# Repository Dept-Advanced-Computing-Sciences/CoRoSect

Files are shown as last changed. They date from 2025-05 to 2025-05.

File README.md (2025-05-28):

# CoRoSect
Results from the Horizon Project CoRoSect

<ul>
     <li>Robot Extension - STEP and mechanical design files for the robot extension used in CoRoSect</li>
     <li>scripts - contains additional scripts and files
     <ul>
       <li>reachability_simulation: URDF design of robot extension and simulation scripts.</li>
       <li>stabilization_secondary_planning_scene: ROS launch files for a secondary MoveIt! environment where iterative stabilisation is performed.</li>
     </ul>
     </li>

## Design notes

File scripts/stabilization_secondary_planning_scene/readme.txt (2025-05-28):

The main script that performs iterative planning for a constrained rail orientation is ins linear_drive_constrained_planning.py. 
It relies on a definition of your robot URDF as a planning group in MoveIt! and referenceing the correct link IDs.
This script can be run individually or through ROS. Through ROS, it opens a service (.srv files are included but need to be compiled).

The new planning scene should be launched in a secondary ROS NAMESPACE to not link the with either the primary MoveIt! planning scene or the real robot.
This is done through the fake_world.launch, which can be included to run automatically within another launch file.

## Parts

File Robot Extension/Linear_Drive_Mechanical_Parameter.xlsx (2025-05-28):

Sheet: LS_Main_Functional_Parameter
Linear drive specs |  |  | Wittenstein CDS040 main motor specs without any gears
Parameter | Symbol | Value | Parameter | Symbol | Value | Parameter | Symbol | Value
Max speed sled | vs_max | 1 m/s | No load speed |  | 5087 rpm
Max travel distance of sled on linear drive | d_max | 0.45 m
Max acceleration of sled | a_max | 3.9 m/s^2 | Max torque |  | 1.02 Nm
Time required by sled to travel 450 mm | t_450 | 0.75 sec | Cont. stall torque |  | 0.32 Nm
 |  |  | Weight |  | 650 g

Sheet: LS_Weight table
Linear slide weight table
# | Part | Weight in grams | Amount | Total | Category | Sub Category
1 | 40x40 V-slot | 604.517 | 1 | 604.517 | Rail Assembly | Aluminium Extrusion
2 | Pulley | 12.189 | 1 | 12.189 | Rail Assembly | Pulleys
3 | PRT-02-20-P | 72.8569 | 1 | 72.8569 |  | Bearings
4 | Wheel Assembly | 24.1229 | 4 | 96.4916 |  | DOF1/Sled
5 | Belt Fastener Assembly | 32.799 | 2 | 65.598 |  | DOF1/Sled
6 | Bottom Sled | 298.839 | 1 | 298.839 |  | Aluminium part - milled
7 | KUKA End | 442.027 | 0 | 0
8 | CDSR-040CHM0-00000-1SG-E | 647.039 | 3 | 1941.117 |  | DOF1
9 | Top Sled | 100.817 | 1 | 100.817 |  | Aluminium part - milled
10 | Bearing | 6.71 | 2 | 13.42 |  | Bearings
11 | Connector Plate Motor | 43.501 | 1 | 43.501 | Rail Assembly
12 | Connector Plate KUKA | 128.117 | 1 | 128.117 | Rail Assembly
13 | RG6 Quickchanger Flange | 56.138 | 1 | 56.138
14 | RG6 | 1352.65 | 1 | 1352.646
15 | Mounting Plate Pulley | 31.655 | 2 | 63.31 | Rail Assembly | Pulleys
16 | Pulley Protection 1 | 78.401 | 1 | 78.401 |  | Printed parts
17 | Pulley Protection 2 | 78.358 | 1 | 78.358 |  | Printed parts
19 | M3x12 Low | 0.8449 | 4 | 3.3796 |  | Screws and bolts
20 | M6x14 Sunken | 2.934 | 8 | 23.472 |  | Screws and bolts
21 | M5x16 Sunken | 2.294 | 8 | 18.352 |  | Screws and bolts
22 | Shaft 2nd DOF | 123.948 | 1 | 123.948
23 | Spacerblock 2nd DOF | 53.729 | 1 | 53.729 |  | Aluminium part - milled
24 | Armature Type 300-SZ04-6Hk7 | 29.541 | 1 | 29.541
25 | SHSWA 15-25 | 33.769 | 2 | 67.538
26 | Adapter RG6 Quickchanger | 61.58 | 1 | 61.58
27 | Ball Bearing SS | 4.131 | 2 | 8.262 |  | Bearings
28 | Spurgear SSY1 90 M | 205.554 | 1 | 205.554 |  | Spurgears
29 | Spurgear SUS1 25J8 | 53.889 | 1 | 53.889 |  | Spurgears
30 | 90370A20T Steel Thin Hex Nut | 0.291 | 3 | 0.873 |  | Screws and bolts
31 | Adapter Plate DOF1 to DOF2 | 30.759 | 1 | 30.759 |  | Aluminium part - milled
32 | 92855A522 18-8 SS | 1.604 | 3 | 4.812 |  | Screws and bolts
33 | Mounting Plate 2nd DOF | 40.227 | 1 | 40.227 |  | Aluminium part - milled
34 | 90965A160 316 SS | 0.175 | 10 | 1.75 |  | Screws and bolts
35 | 90037A119 316 HS | 1.286 | 4 | 5.144 |  | Screws and bolts
36 | Brake Krendion PM Line 86 61 | 176.89 | 1 | 176.89
37 | 9375A195 18-8 SS | 0.018 | 6 | 0.108 |  | Screws and bolts
38 | 91292A834 18-8 SS | 0.137 | 6 | 0.822 |  | Screws and bolts
39 | Spurgear SSG1 20J8 | 29.432 | 1 | 29.432 |  | Spurgears
40 | MLHS10 | 5.093 | 1 | 5.093
41 | Spurgear SSG1 80C | 221.019 | 1 | 221.019 |  | Spurgears
42 | DOF2 Mount | 110.093 | 1 | 110.093 |  | Aluminium part - milled
43 | DOF2 Mount 18-8 SS Hex | 0.282 | 4 | 1.128 |  | Screws and bolts
44 | 90751A123 18-8 SS | 1.438 | 6 | 8.628 |  | Screws and bolts
45 | End Stop Bar | 4.688 | 2 | 9.376 |  | Aluminium part - ordered
46 | Bird drinker/Feader | 1309.339 | 0 | 0
 |  |  |  | 6301.7151 | gr.

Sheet: LS_Inertias_and_Torques
Linear Drive Moments and Inertias and Moments of Inertias
Part/ Assembly | Weight | Moment of Inertia around movement axis [gmm^2] | [kgcm^2] | [kgm^2] | Load torque TL* | Acc. Torque Ta* | Total Torque*
Full linear drive assembly | 6136 g | - | - | - | - | -
Full linear drive assembly with filled bird drinker | 7436 g | - | - | - | - | -
Sledge with dof 2 (yawing) and dof 3 (tilting) incl RG6 | 4560 g | - | - | - | - | -
Sledge with dof 2 and dof 3 incl RG6 + Filled bird drinker | 5870.1 g | - | - | - | - | -
Dof 2 (Yawing) with RG6 in vert. position | 3318.4 g | 7.255*10^6 | 0.7 (72.55) | 0.00073 (0.0073) | - | -
Dof 2 (Yawing) with RG6 in hor. position | 3318.4 g | 3.539*10^7 | 3.6 (360??) | 0.00036 (0.035) | - | 1.02 Nm ( @t_t=0.5 sec, d_t=90° a=28.3 rad/sec^2) | 1.53 Nm T=(Ta+TL)*Sf with Sf=1.5
Dof 2 (Yawing) with RG6 in vert. position + filled bird drinker | 4627.7 g | 1.009*10^7 | 1 (100) | 0.0001 (0.01) | - | -
Dof 2 (Yawing) with RG6 in hor. position + filled bird drinker | 4627.7 g | 1.457*10^8 | 14.6 (1500) | 0.00146 (0.15) | - | 0.041 Nm ( @t_t=0.5 sec, d_t=90° a=28.3 rad/sec^2) | 0.0620 Nm T=(Ta+TL)*Sf with Sf=1.5
Dof3 (Tilting) with RG6 | 1917.5 g | 1.158*10^7 | 1.2 (120) | 0.00012 (0.012) | 1.63 Nm (@hor. Pos.,@COM to shaft distance = 0.1 m, @1.66 kg) | 0.034 Nm ( @t_t=0.5 sec, d_t=90° a=28.3 rad/sec^2) | 1.66 Nm T=(Ta+TL)*Sf with Sf=1.5
Dof3 (Tilting) with RG6 + filled bird drinker | 3226.8 g | 4.480*10^7 | 4.5 (450) | 0.00045 (0.045) | 5.48 Nm (@hor. Pos.,@COM to shaft distance = 0.188 m, @2.97 kg) | 0.13 Nm ( @t_t=0.5 sec, d_t=90° a=28.3 rad/sec^2) | 5.61 Nm T=(Ta+TL)*Sf with Sf=1.5
 |  |  |  | *Torques required without considering gear ratios. To get torques required by the motors divide the torque values by the corresponding gear ratios
Torques on KUKA iiwa joint A6
Configuration | Total weight of drive [Kg] | Distance of COM to A6 [m] | Static torque on A6 [N] | Dyn. torque [N] =stat. torque * 1.5
Drive at farest position from flange, gripper in hor. position point away from robot arm and parallel to drive, no bird drinker or other load | 7.32 | 0.266 | 19.1012472 | 28.6518708
Drive at farest position from flange, gripper in hor. position point away from robot arm and parallel to drive, with filled bird drinker | 8.6 |  | 0 | 0

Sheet: LS_Gear_transmissions
Linear Drive Gear transmission ratios
 | Ratio | Gear Ø [mm] | Pinion Ø [mm]
Dof 1 (Linear drive) | - | - | -
Dof 2 (Yawing) | 1 : 3.6 | 90 | 25
Dof 3 (Tilting) | 1 : 4 | 80 | 20

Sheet: LS_End_stop_switches
OMRON Mechanical Touch Switch D5B (supplier: MISUMI)
https://uk.misumi-ec.com/vona2/detail/221000559295/?CategorySpec=00000033026%3a%3aa
Please find the data sheet in the documentation
Switch specs
Purpose: | End switches of linear drive for homing and safety
Version | D5B-5013 (hemispheric actuator, 3m cable, M5 type)
Weight | 14 g
Max. operating force | 0.74 N
Max. permissible operating force | 1.96 N
Max. force (before breaking) | 14.7 N
Impact forces and speeds for different scenarios
Given: | Symbol | Value
weight sled + dof 2 + dof 3 + RG6 | ms_1 | 4.56 kg
weight sled + dof 2 + dof 3 + RG6+ bird drinker | ms_2 | 5.86 kg
max speed sled | vs_max | 1 m/s
max travel distance of sled on linear drive | d_max | 0.45 m
Formulars used:
Impact force | F_imp = (0.5*m*v^2)/d
Travel speed to get certain impact force | v = sqrt((2*F*d)/m)
Results:
Max impact force without bird drinker | Fmax_1 | 5 N
Max impact force with bird drinker | Fmax_2 | 6.51 N
Sled speed for staying below max. operating force | vmax_op | < 0.38 m/s
Sled speed for staying below max. permissible operating force | vmax_perm | < 0.68 m/s

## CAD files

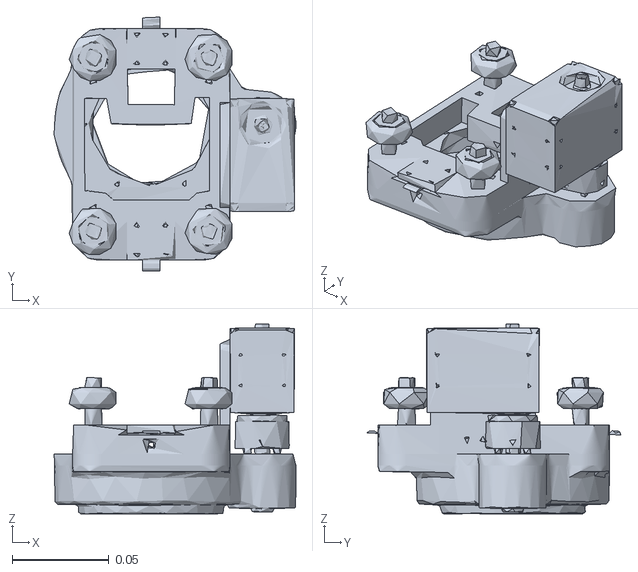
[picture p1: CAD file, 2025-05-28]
scripts/reachability_simulation/urdf/meshes/Linear Drive Sept2023/Sledge Assembly.stl
0.125 x 0.132 x 0.0984

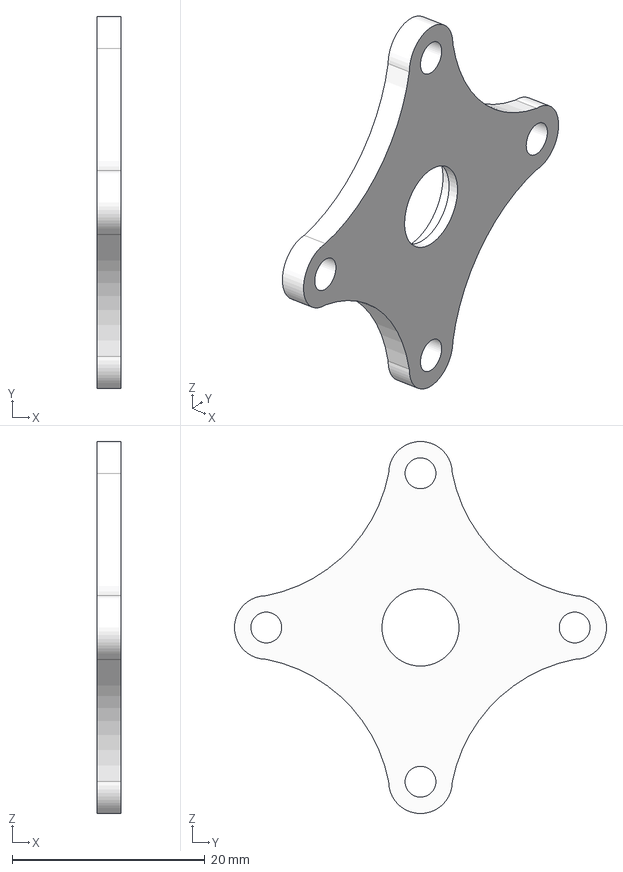
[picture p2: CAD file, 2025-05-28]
Robot Extension/technical_drawings_and_STEP/DOF 1 Guide Rail/DOF1 Bearing Mount.step
2.50 x 38.6 x 38.6 mm

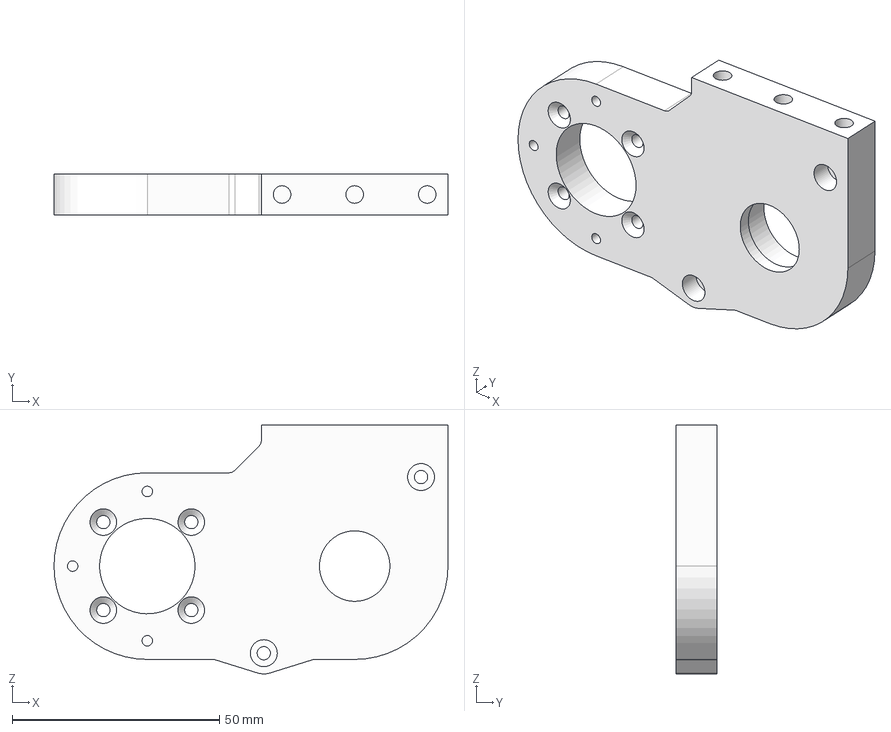
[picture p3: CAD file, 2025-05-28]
Robot Extension/technical_drawings_and_STEP/DOF 2/Motor Mount 2DOF.step
95.0 x 10.0 x 60.0 mm

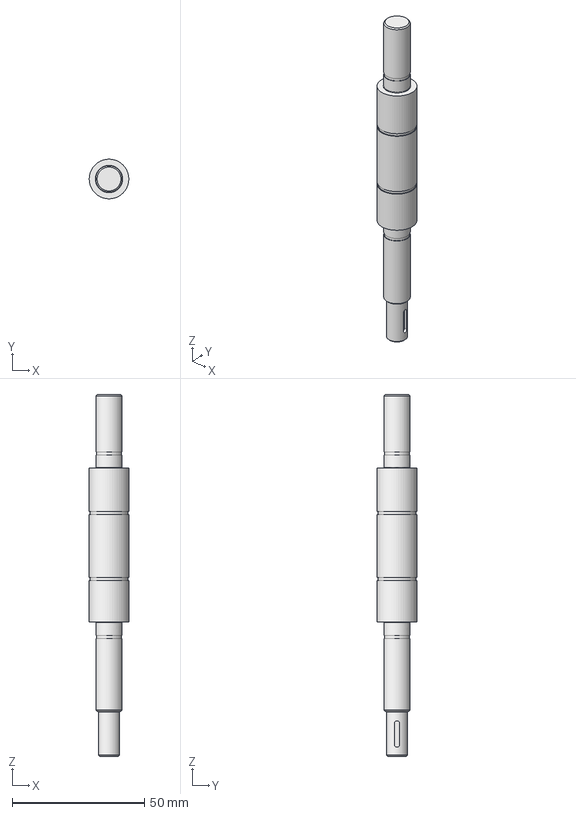
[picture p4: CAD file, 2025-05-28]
Robot Extension/technical_drawings_and_STEP/DOF 3/Shaft 2DOF.step
15.0 x 15.0 x 136.9 mm

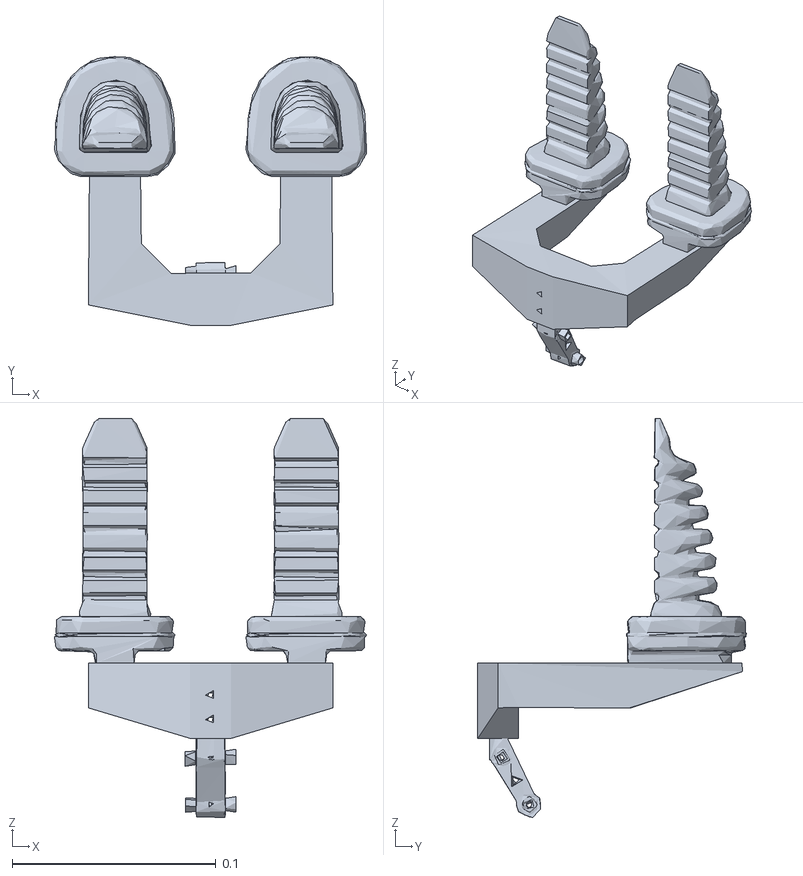
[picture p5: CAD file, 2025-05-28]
scripts/reachability_simulation/urdf/meshes/End Effector Designs/soft_gripper_rg6_finger_LARGE.stl
0.153 x 0.132 x 0.196

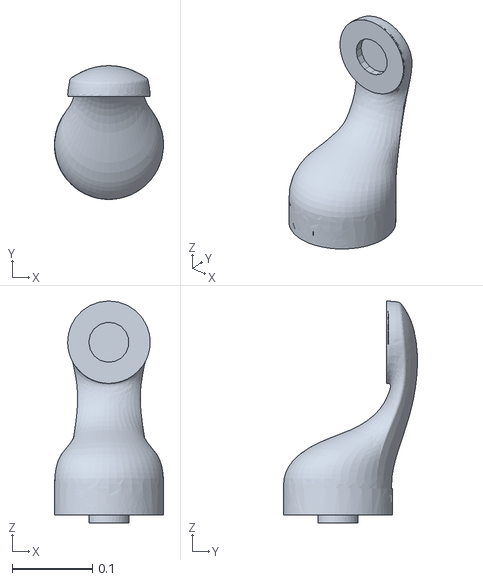
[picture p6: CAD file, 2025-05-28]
scripts/reachability_simulation/urdf/meshes/iiwa14/collision/link_5.stl
0.136 x 0.167 x 0.277

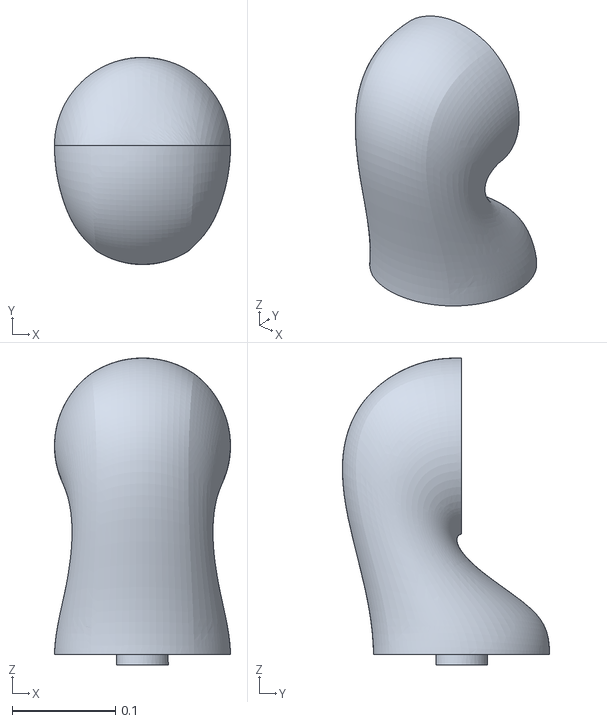
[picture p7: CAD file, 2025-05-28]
scripts/reachability_simulation/urdf/meshes/iiwa14/visual/link_1.stl
0.171 x 0.201 x 0.298

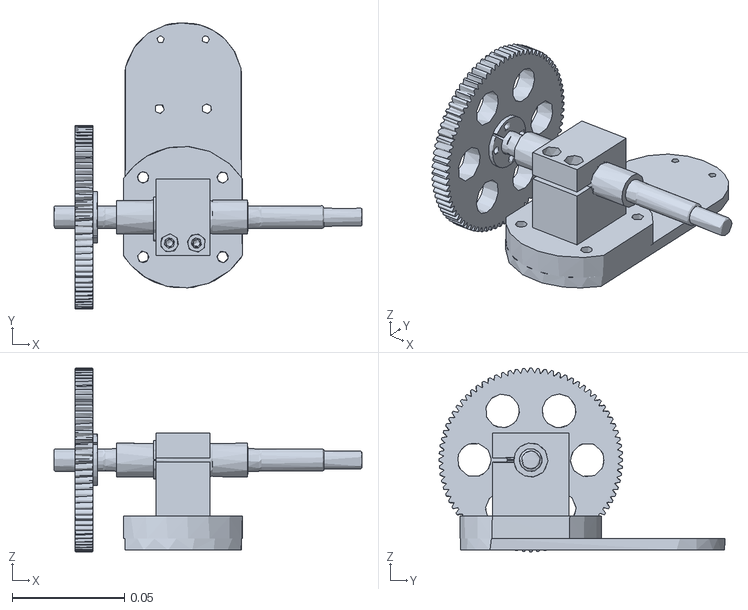
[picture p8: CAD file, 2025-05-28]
scripts/reachability_simulation/urdf/meshes/Linear Drive Sept2023/3DOF.stl
0.137 x 0.127 x 0.0817

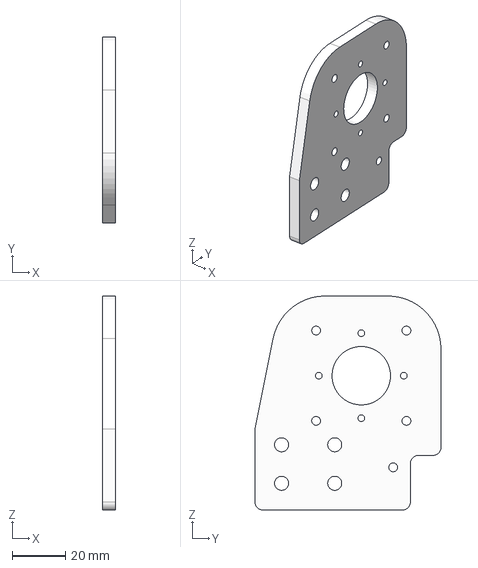
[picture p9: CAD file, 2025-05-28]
Robot Extension/technical_drawings_and_STEP/DOF 1 Guide Rail/DOF1 Motor and Shaft Mount.step
5.00 x 70.0 x 80.5 mm

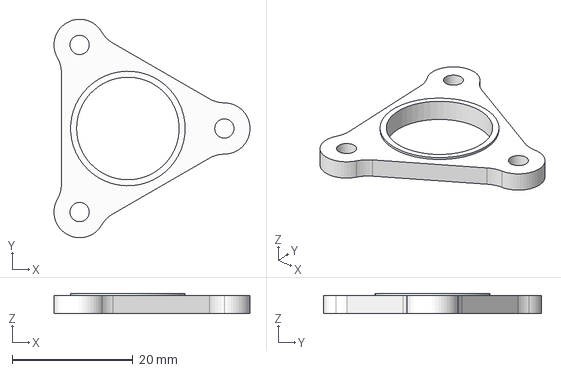
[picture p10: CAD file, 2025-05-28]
Robot Extension/technical_drawings_and_STEP/DOF 2/Bearing Brake Cover 2DOF.step
32.5 x 36.2 x 3.35 mm

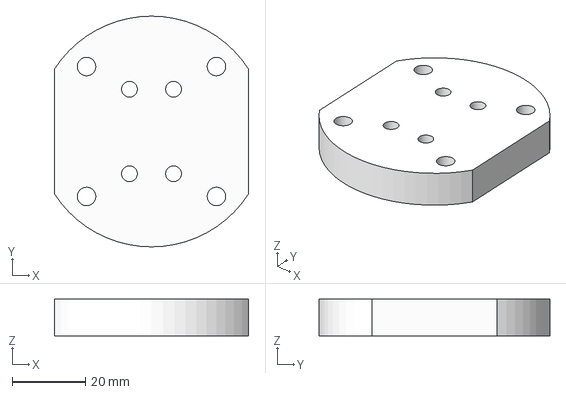
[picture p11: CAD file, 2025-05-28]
Robot Extension/technical_drawings_and_STEP/DOF 3/Adapter Plate RG6-Shaft.step
52.8 x 62.8 x 10.0 mm

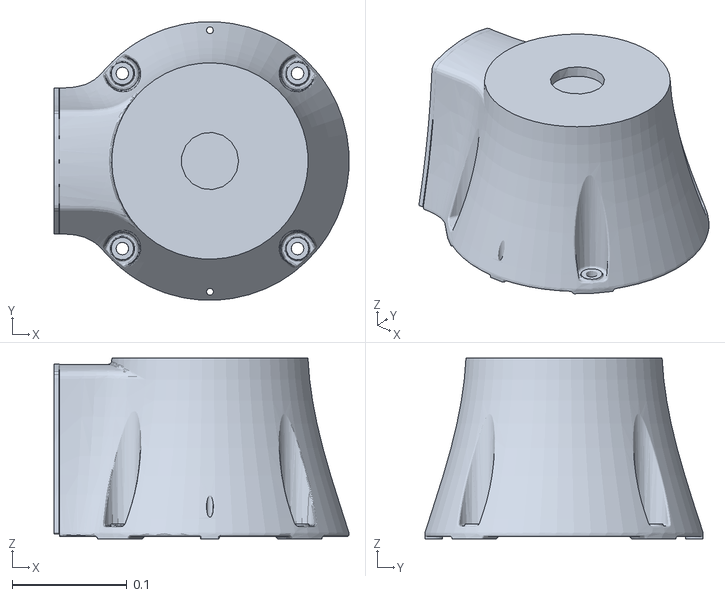
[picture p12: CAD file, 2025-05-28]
scripts/reachability_simulation/urdf/meshes/iiwa14/collision/link_0.stl
0.257 x 0.243 x 0.158

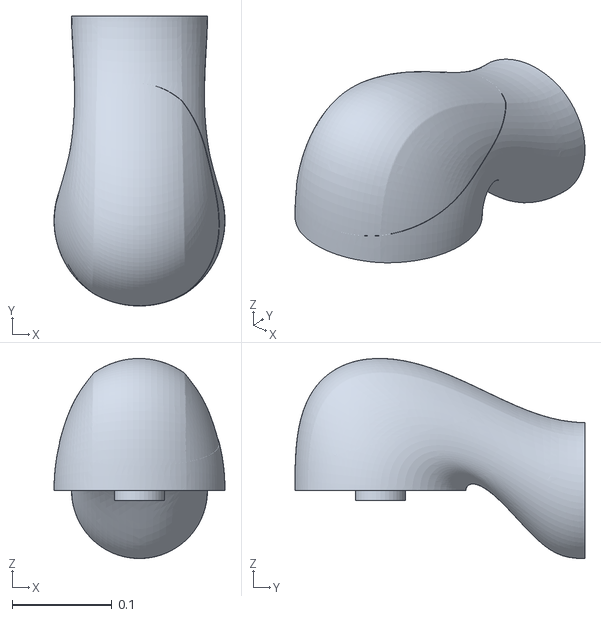
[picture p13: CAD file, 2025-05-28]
scripts/reachability_simulation/urdf/meshes/iiwa14/visual/link_2.stl
0.171 x 0.29 x 0.2

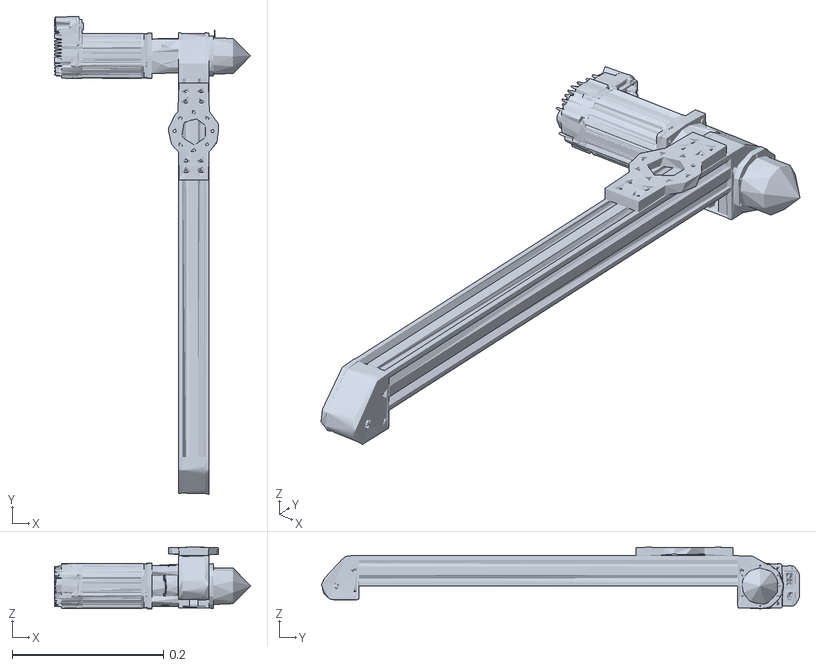
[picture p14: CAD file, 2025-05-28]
scripts/reachability_simulation/urdf/meshes/Linear Drive Sept2023/Guide Rail.stl
0.259 x 0.632 x 0.0815

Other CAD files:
Robot Extension/technical_drawings_and_STEP/DOF 1 Guide Rail/DOF1 Motor Shaft 6mm.step
Robot Extension/technical_drawings_and_STEP/DOF 2/Adapter Plate SpurGear-Base Plate.step
scripts/reachability_simulation/urdf/meshes/iiwa14/collision/link_6.stl
scripts/reachability_simulation/urdf/meshes/iiwa14/visual/link_4.stl
Robot Extension/technical_drawings_and_STEP/DOF 1 Guide Rail/DOF1 CDSR Mounting Plate.step
Robot Extension/technical_drawings_and_STEP/DOF 1 Guide Rail/DOF1 CPM Mounting Plate.step
Robot Extension/technical_drawings_and_STEP/DOF 1 Guide Rail/DOF1 Shaft Mount.step
Robot Extension/technical_drawings_and_STEP/DOF 1 Guide Rail/Rail-Kuka Connector Plate.step
Robot Extension/technical_drawings_and_STEP/DOF 2/Base Plate 2DOF.step
Robot Extension/technical_drawings_and_STEP/DOF 2/Break Mount 2DOF.step
scripts/reachability_simulation/urdf/meshes/Linear Drive Sept2023/2 DOF.stl
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

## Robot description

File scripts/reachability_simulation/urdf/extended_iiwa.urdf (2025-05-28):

<?xml version="1.0" ?>
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
<robot name="m_robot">
    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
    <link name="m_robot_link_0">
        <inertial>
            <origin rpy="0 0 0" xyz="-0.1 0 0.07" />
            <mass value="5" />
            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
        </inertial>
        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
        <self_collision_checking>
            <origin rpy="0 0 0" xyz="0 0 0" />
            <geometry>
                <capsule length="0.25" radius="0.15" />
            </geometry>
        </self_collision_checking>
    </link>
    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
    <joint name="m_robot_joint_1" type="revolute">
        <parent link="m_robot_link_0" />
        <child link="m_robot_link_1" />
        <origin rpy="0 0 0" xyz="0 0 0.1575" />
        <axis xyz="0 0 1" />
        <limit effort="300" lower="-2.9321531433504737" upper="2.9321531433504737" velocity="10" />
        <safety_controller k_position="100" k_velocity="2" soft_lower_limit="-2.8448866807507573" soft_upper_limit="2.8448866807507573" />
        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
        <dynamics damping="0.5" />
    </joint>
    <link name="m_robot_link_1">
        <inertial>
            <origin rpy="0 0 0" xyz="0 -0.03 0.12" />
            <mass value="4" />
            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
        </inertial>
        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
    </link>
    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
    <joint name="m_robot_joint_2" type="revolute">
        <parent link="m_robot_link_1" />
        <child link="m_robot_link_2" />
        <origin rpy="1.5707963267948966 0 3.141592653589793" xyz="0 0 0.2025" />
        <axis xyz="0 0 1" />
        <limit effort="300" lower="-2.0594885173533086" upper="2.0594885173533086" velocity="10" />
        <safety_controller k_position="100" k_velocity="2" soft_lower_limit="-1.9722220547535925" soft_upper_limit="1.9722220547535925" />
        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
        <dynamics damping="0.5" />
    </joint>
    <link name="m_robot_link_2">
        <inertial>
            <origin rpy="0 0 0" xyz="0.0003 0.059 0.042" />
            <mass value="4" />
            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
        </inertial>
        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
    </link>
    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
    <joint name="m_robot_joint_3" type="revolute">
        <parent link="m_robot_link_2" />
        <child link="m_robot_link_3" />
        <origin rpy="1.5707963267948966 0 3.141592653589793" xyz="0 0.2045 0" />
        <axis xyz="0 0 1" />
        <limit effort="300" lower="-2.9321531433504737" upper="2.9321531433504737" velocity="10" />
        <safety_controller k_position="100" k_velocity="2" soft_lower_limit="-2.8448866807507573" soft_upper_limit="2.8448866807507573" />
        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
        <dynamics damping="0.5" />
    </joint>
    <link name="m_robot_link_3">
        <inertial>
            <origin rpy="0 0 0" xyz="0 0.03 0.13" />
            <mass value="3" />
            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
        </inertial>
        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
    </link>
    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
    <joint name="m_robot_joint_4" type="revolute">
        <parent link="m_robot_link_3" />
        <child link="m_robot_link_4" />
        <origin rpy="1.5707963267948966 0 0" xyz="0 0 0.2155" />
        <axis xyz="0 0 1" />
        <limit effort="300" lower="-2.0594885173533086" upper="2.0594885173533086" velocity="10" />
        <safety_controller k_position="100" k_velocity="2" soft_lower_limit="-1.9722220547535925" soft_upper_limit="1.9722220547535925" />
        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
        <dynamics damping="0.5" />
    </joint>
    <link name="m_robot_link_4">
        <inertial>
            <origin rpy="0 0 0" xyz="0 0.067 0.034" />
            <mass value="2.7" />
            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
        </inertial>
        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
    </link>
    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
    <joint name="m_robot_joint_5" type="revolute">
        <parent link="m_robot_link_4" />
        <child link="m_robot_link_5" />
        <origin rpy="-1.5707963267948966 3.141592653589793 0" xyz="0 0.1845 0" />
        <axis xyz="0 0 1" />
        <limit effort="300" lower="-1.7453292519943295" upper="1.7453292519943295" velocity="10" />
        <safety_controller k_position="100" k_velocity="2" soft_lower_limit="-1.5707963267948966" soft_upper_limit="1.5707963267948966" />
        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
        <dynamics damping="0.5" />
    </joint>
    <link name="m_robot_link_5">
        <inertial>
            <origin rpy="0 0 0" xyz="0.0001 0.021 0.076" />
            <mass value="1.7" />
            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
        </inertial>
        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
    </link>
    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
    <joint name="m_robot_joint_6" type="revolute">
        <parent link="m_robot_link_5" />
        <child link="m_robot_link_6" />
        <origin rpy="1.5707963267948966 0 0" xyz="0 0 0.2155" />
        <axis xyz="0 0 1" />
        <limit effort="300" lower="-2.0094885173533086" upper="2.0094885173533086" velocity="10" />
        <safety_controller k_position="100" k_velocity="2" soft_lower_limit="-1.9722220547535925" soft_upper_limit="1.9722220547535925" />
        <dynamics damping="0.5" />
    </joint>
    <link name="m_robot_link_6">
        <inertial>
            <origin rpy="0 0 0" xyz="0 0.0006 0.0004" />
            <mass value="1.8" />
            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
        </inertial>
        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
    </link>
    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
    <joint name="m_robot_joint_7" type="revolute">
        <parent link="m_robot_link_6" />
        <child link="m_robot_link_7" />
        <origin rpy="-1.5707963267948966 3.141592653589793 0" xyz="0 0.081 0" />
        <axis xyz="0 0 1" />
        <limit effort="300" lower="-3.0543261909900763" upper="3.0543261909900763" velocity="10" />
        <safety_controller k_position="100" k_velocity="2" soft_lower_limit="-3.01941960595019" soft_upper_limit="3.01941960595019" />
        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
        <dynamics damping="0.5" />
    </joint>
    <link name="m_robot_link_7">
        <inertial>
            <origin rpy="0 0 0" xyz="0 0 0.02" />
            <mass value="0.3" />
            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
        </inertial>
        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
    </link>
    <joint name="m_robot_joint_ee" type="fixed">
        <parent link="m_robot_link_7" />
        <child link="m_robot_link_ee" />
        <origin rpy="0 0 0" xyz="0 0 0.045" />
    </joint>
    <link name="m_robot_link_ee" />
    <joint name="m_robot_link_ee_m_robot_joint_ee" type="fixed">
        <origin rpy="3.14159 0 1.5707963267948966" xyz="0.07 0 0.043" />
        <parent link="m_robot_link_ee" />
        <child link="m_robot_linear_drive_guiderail" />
    </joint>
    <link name="m_robot_linear_drive_guiderail">
        <inertial>
            <origin rpy="0 0 0" xyz="0 0 0" />
            <mass value="0.01" />
            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
        </inertial>
        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
    </link>
    <joint name="m_robot_linear_drive_guiderail_sledge_joint" type="prismatic">
        <origin rpy="0 0 3.14159" xyz="0 -0.12 -0.022" />
        <parent link="m_robot_linear_drive_guiderail" />
        <child link="m_robot_linear_drive_sledge" />
        <limit effort="1" lower="0.0" upper="0.33" velocity="0.3" />
        <axis xyz="0 1 0" />
    </joint>
    <link name="m_robot_linear_drive_sledge">
        <inertial>
            <origin rpy="0 0 0" xyz="0 0 0" />
            <mass value="0.01" />
            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
        </inertial>
        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
    </link>
    <joint name="m_robot_linear_drive_sledge_dof1_joint" type="revolute">
        <origin rpy="0 0 0" xyz="0 0 -0.015" />
        <parent link="m_robot_linear_drive_sledge" />
        <child link="m_robot_linear_drive_dof1" />
        <axis xyz="0 0 1" />
        <limit effort="1" lower="-1.571" upper="1.571" velocity="1.571" />
    </joint>
    <link name="m_robot_linear_drive_dof1">
        <inertial>
            <origin rpy="0 0 0" xyz="0 0 0" />
            <mass value="0.01" />
            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
        </inertial>
        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
    </link>
    <joint name="m_robot_linear_drive_dof1_dof2_joint" type="revolute">
        <origin rpy="0 0 0" xyz="0 0 -0.071" />
        <parent link="m_robot_linear_drive_dof1" />
        <child link="m_robot_linear_drive_dof2" />
        <axis xyz="1 0 0" />
        <limit effort="1" lower="-1.571" upper="0.0" velocity="1.571" />
    </joint>
    <link name="m_robot_linear_drive_dof2">
        <inertial>
            <origin rpy="0 0 0" xyz="0 0 0" />
            <mass value="0.01" />
            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
        </inertial>
        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
    </link>
    <joint name="m_robot_linear_drive_joint_ee" type="fixed">
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

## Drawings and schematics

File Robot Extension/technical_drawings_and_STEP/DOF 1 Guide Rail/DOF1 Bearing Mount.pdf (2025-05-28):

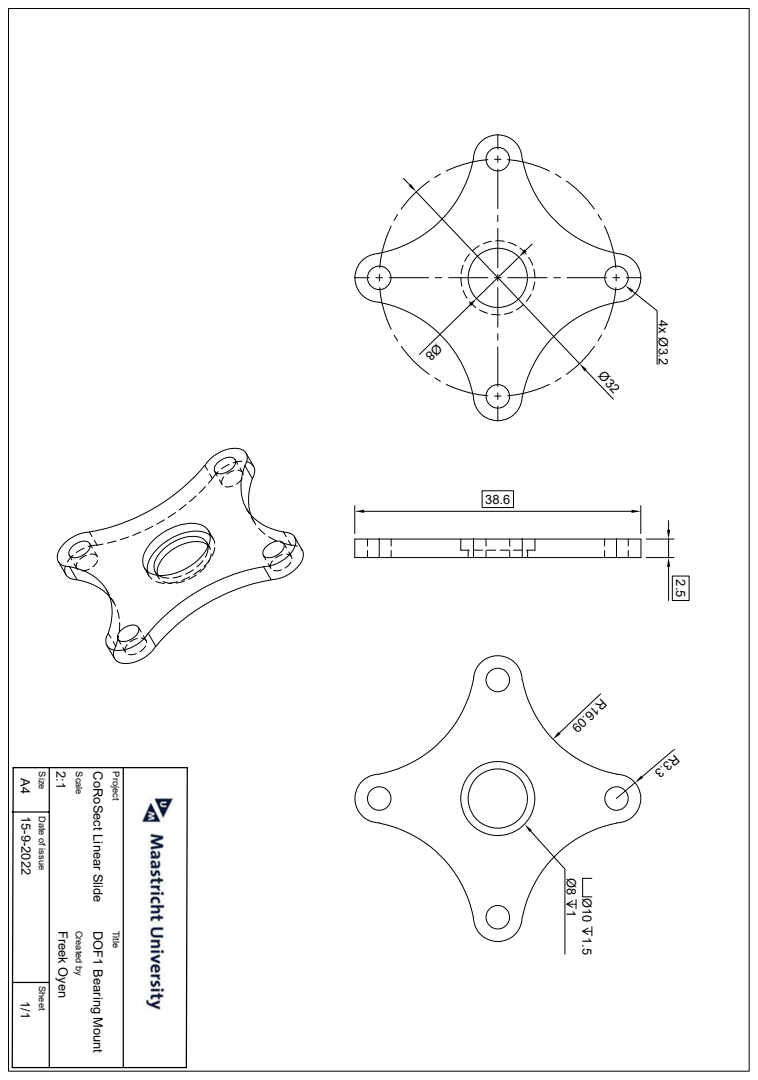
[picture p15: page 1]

Created by Project Date of issue Sheet Size Scale Title 15-9-2022 1/1 CoRoSect Linear Slide Freek Oyen 2:1A4 DOF1 Bearing Mount

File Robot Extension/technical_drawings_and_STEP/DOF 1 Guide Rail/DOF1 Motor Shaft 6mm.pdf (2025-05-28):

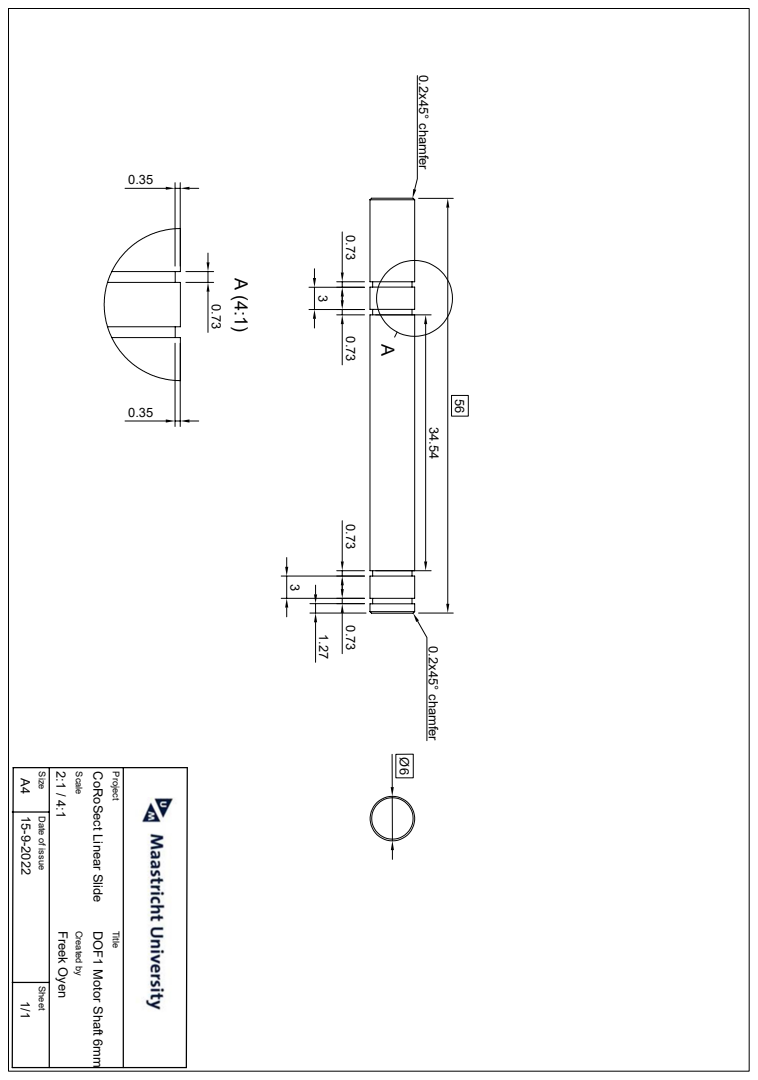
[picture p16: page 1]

Created by Project Date of issue Sheet Size Scale Title 15-9-2022 1/1 CoRoSect Linear Slide Freek Oyen 2:1 / 4:1 A4 DOF1 Motor Shaft 6mm 56 1.27 0.73 3 0.73 0.73 3 0.73 34.54 0.2x45° chamfer 0.2x45° chamfer Ø6 A A (4:1)

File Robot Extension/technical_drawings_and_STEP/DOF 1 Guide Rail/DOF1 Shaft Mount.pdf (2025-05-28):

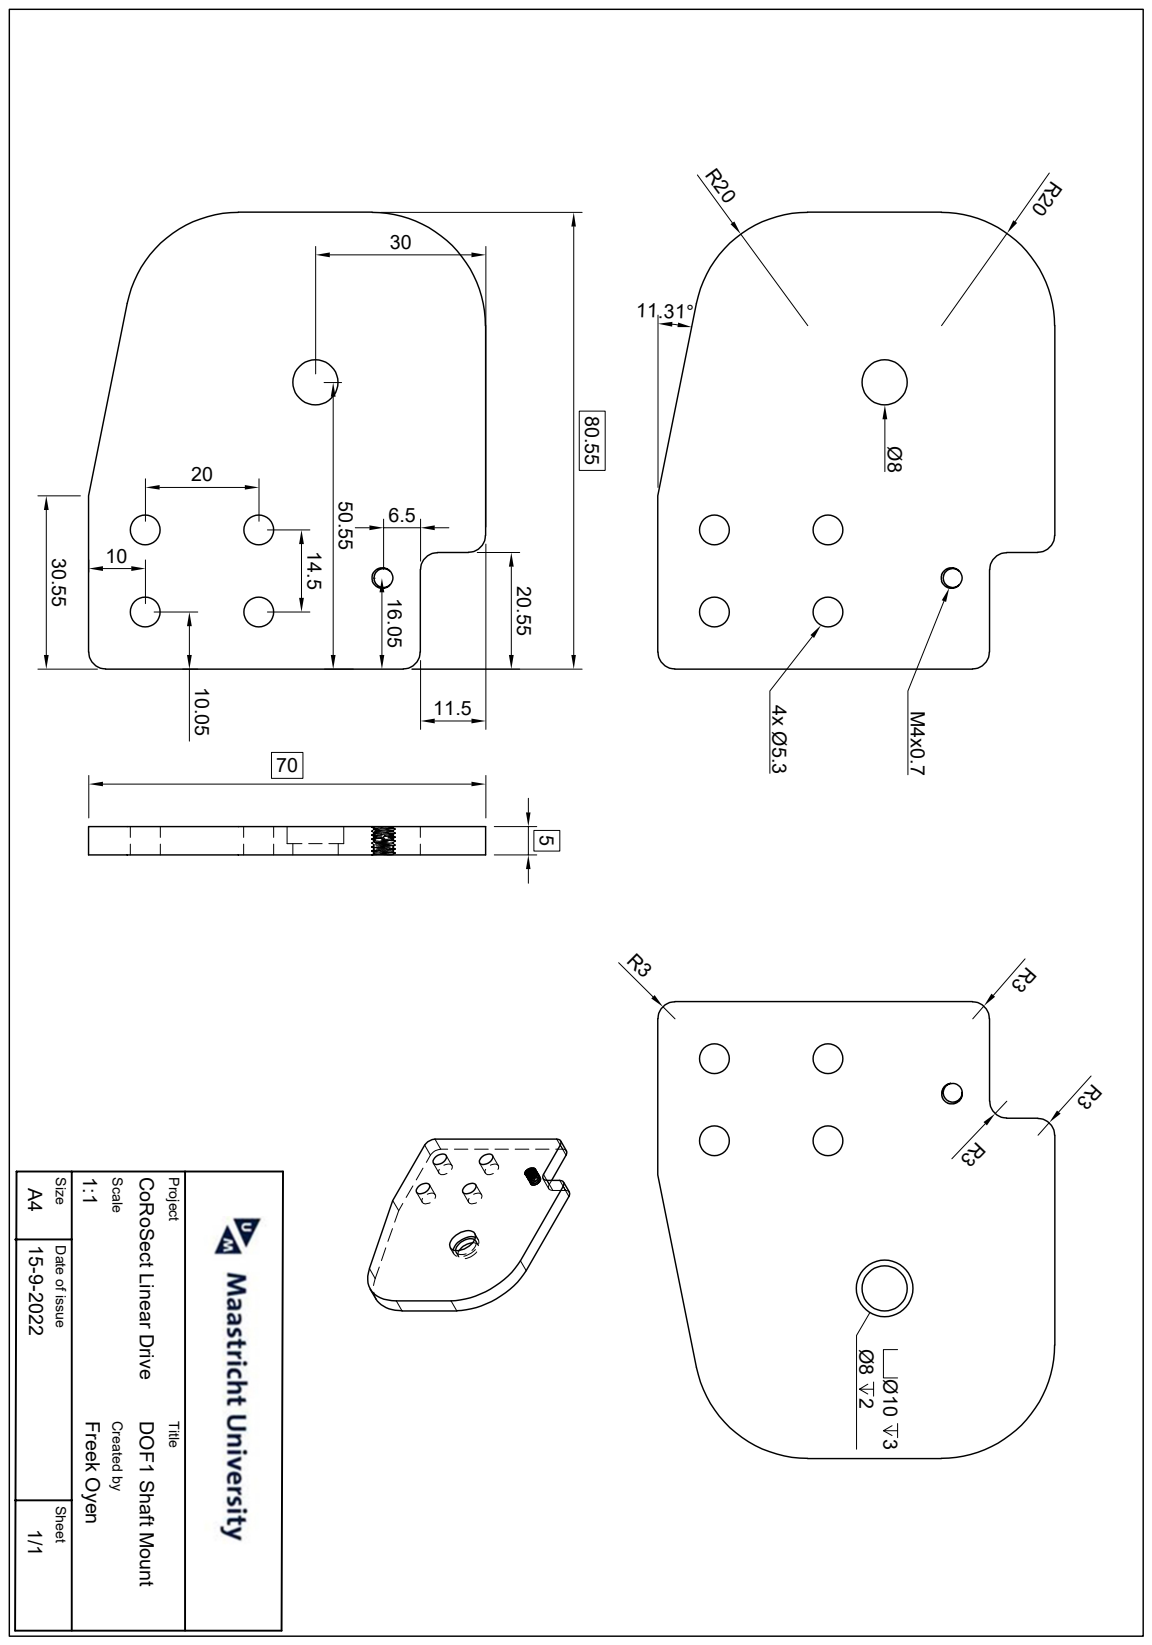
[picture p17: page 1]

Created by Project Date of issue Sheet Size Scale Title 15-9-2022 1/1 CoRoSect Linear Drive Freek Oyen 1:1A4 DOF1 Shaft Mount 80.55

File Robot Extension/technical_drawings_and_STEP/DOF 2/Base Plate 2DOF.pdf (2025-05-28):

38.5 22.5

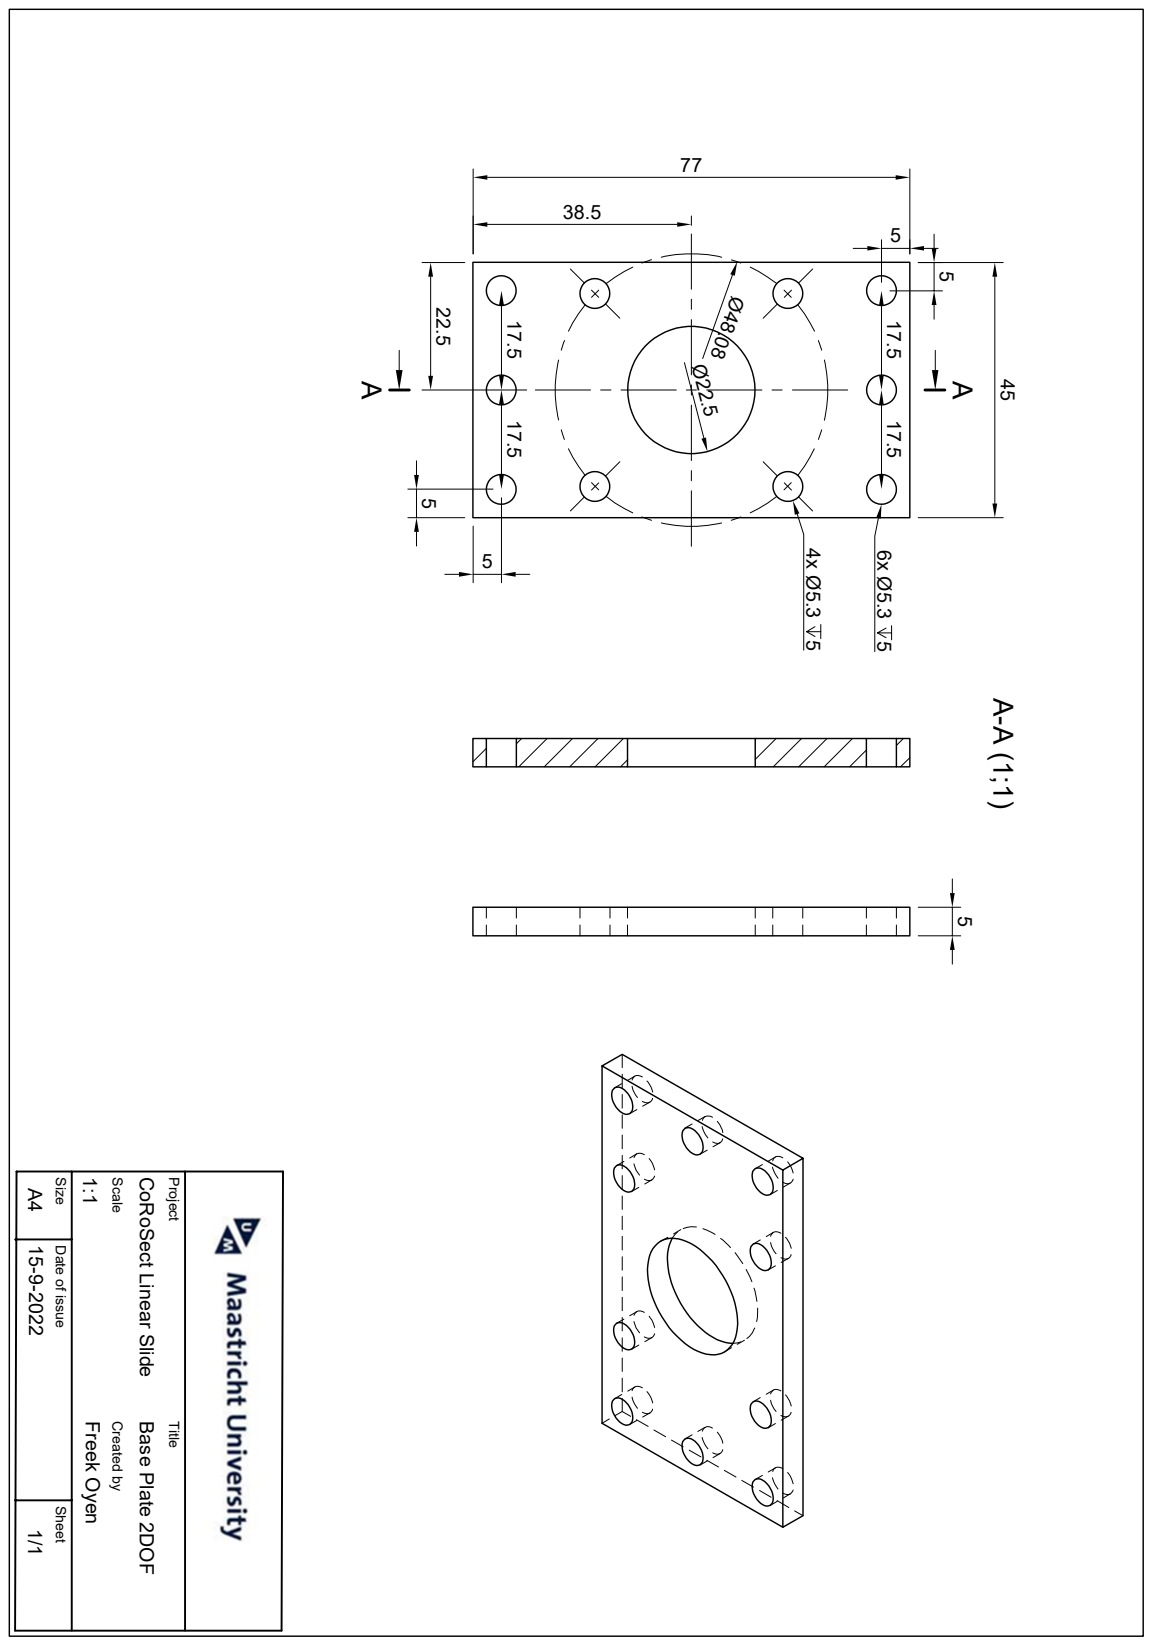
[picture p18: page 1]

Created by Project Date of issue Sheet Size Scale Title 15-9-2022 1/1 CoRoSect Linear Slide Freek Oyen 1:1A4 Base Plate 2DOF 45

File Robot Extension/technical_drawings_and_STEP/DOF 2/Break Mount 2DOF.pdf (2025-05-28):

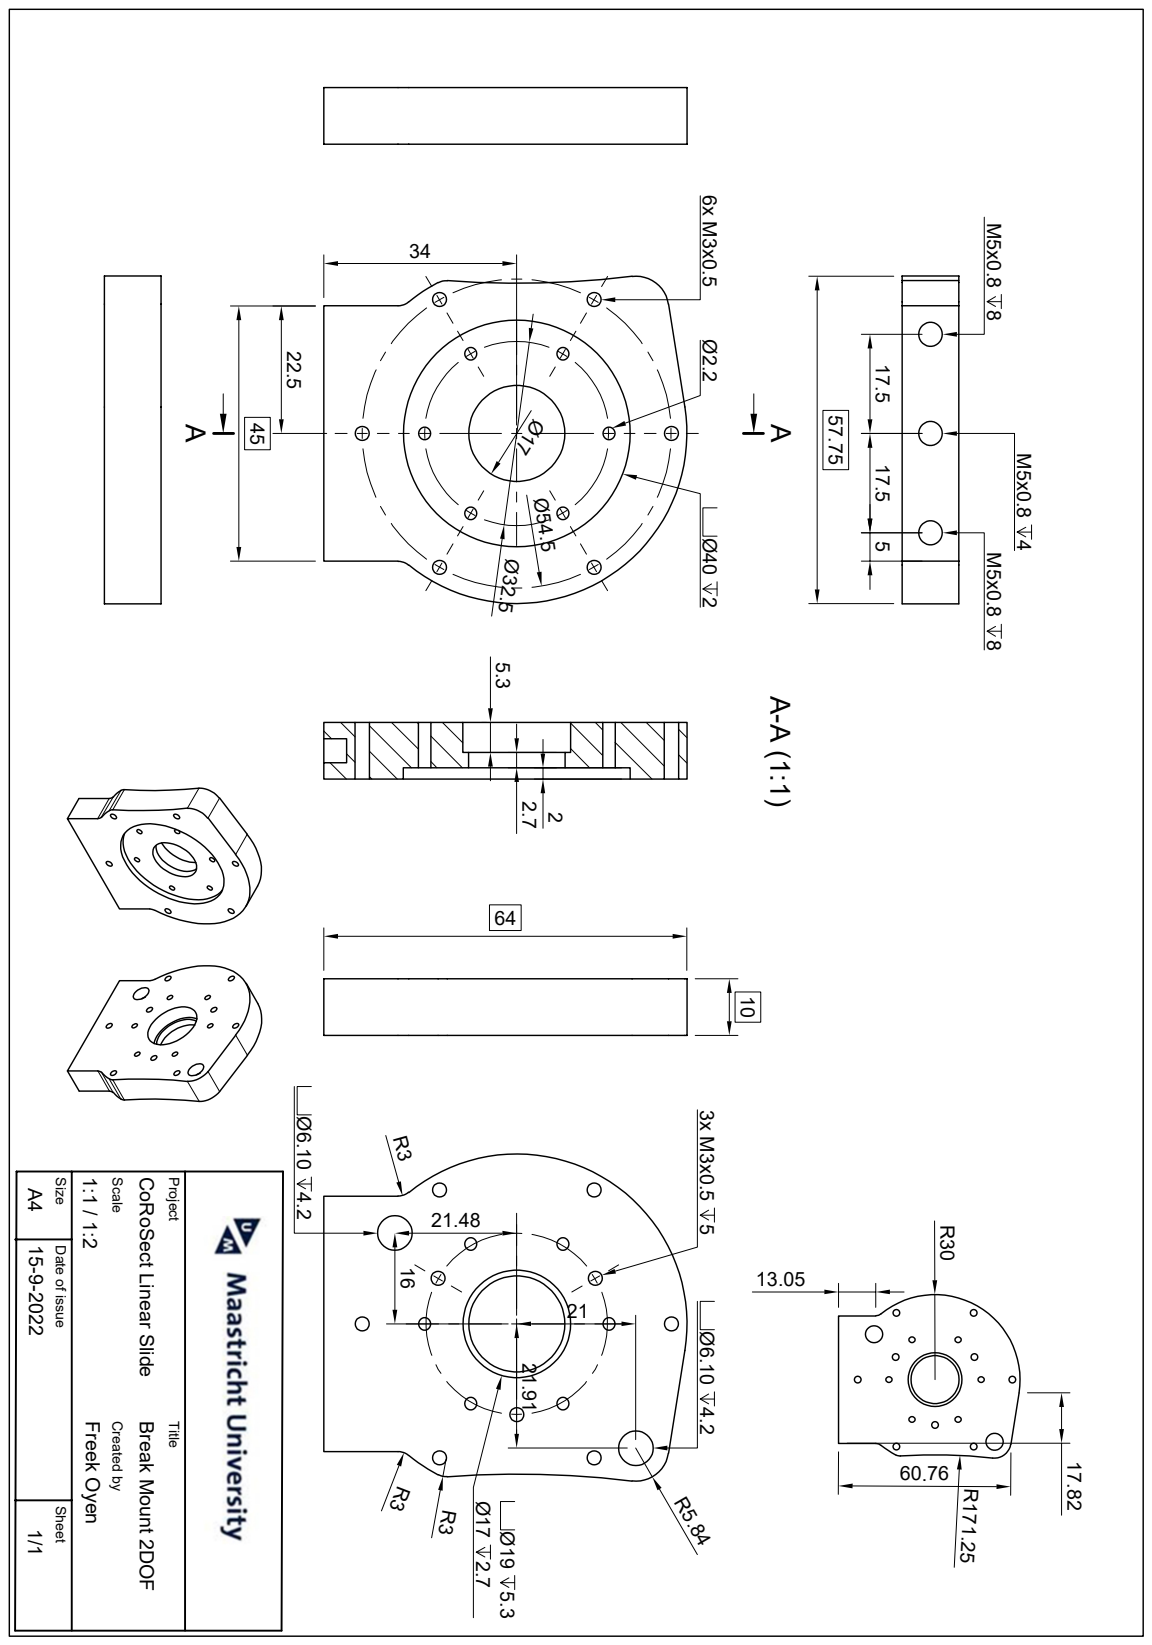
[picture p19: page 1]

Created by Project Date of issue Sheet Size Scale Title 15-9-2022 1/1 CoRoSect Linear Slide Freek Oyen 1:1 / 1:2 A4 Break Mount 2DOF 45 10

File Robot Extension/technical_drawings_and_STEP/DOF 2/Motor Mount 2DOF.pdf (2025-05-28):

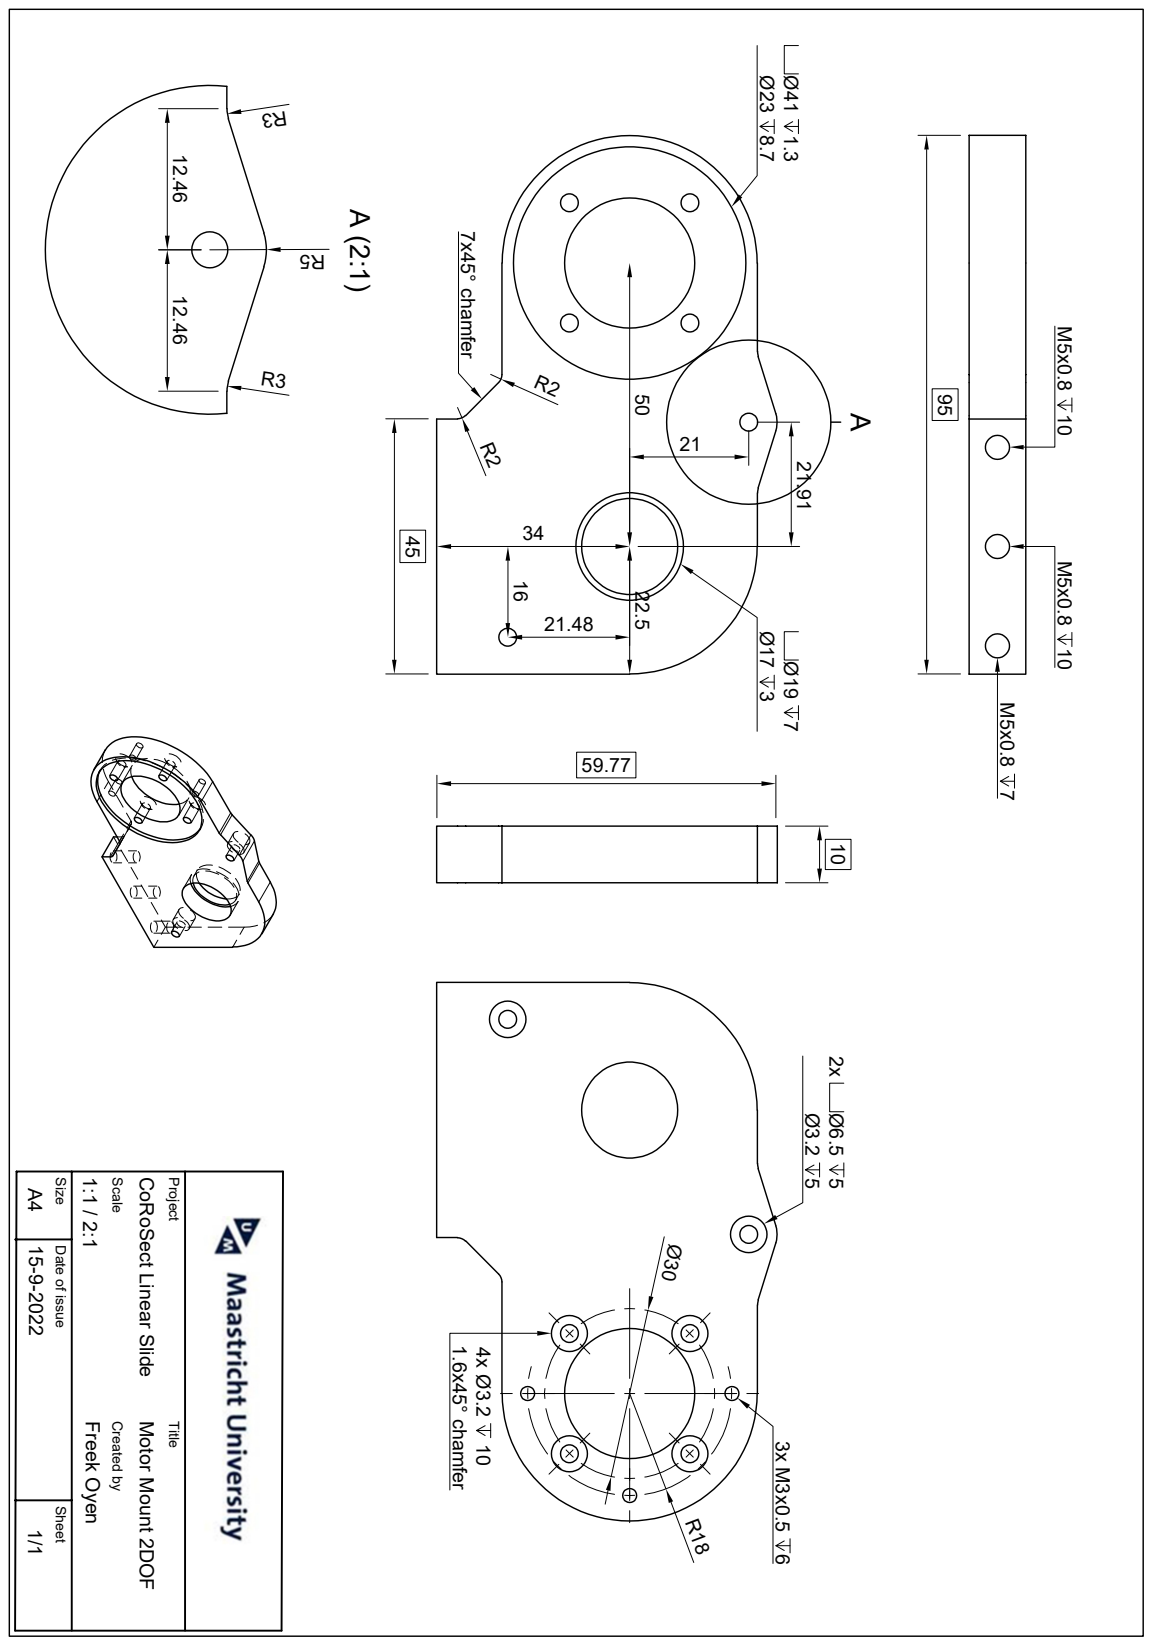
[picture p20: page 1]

Created by Project Date of issue Sheet Size Scale Title 15-9-2022 1/1 CoRoSect Linear Slide Freek Oyen 1:1 / 2:1 A4 Motor Mount 2DOF 4534 22.5 50 Ø19 7 Ø17 3 Ø41 1.3 Ø23 8.7 21.91

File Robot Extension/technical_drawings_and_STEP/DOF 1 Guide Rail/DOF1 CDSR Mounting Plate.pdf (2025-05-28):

# 58 5 chamfer 4x 2.2x45° R12 ²⁹

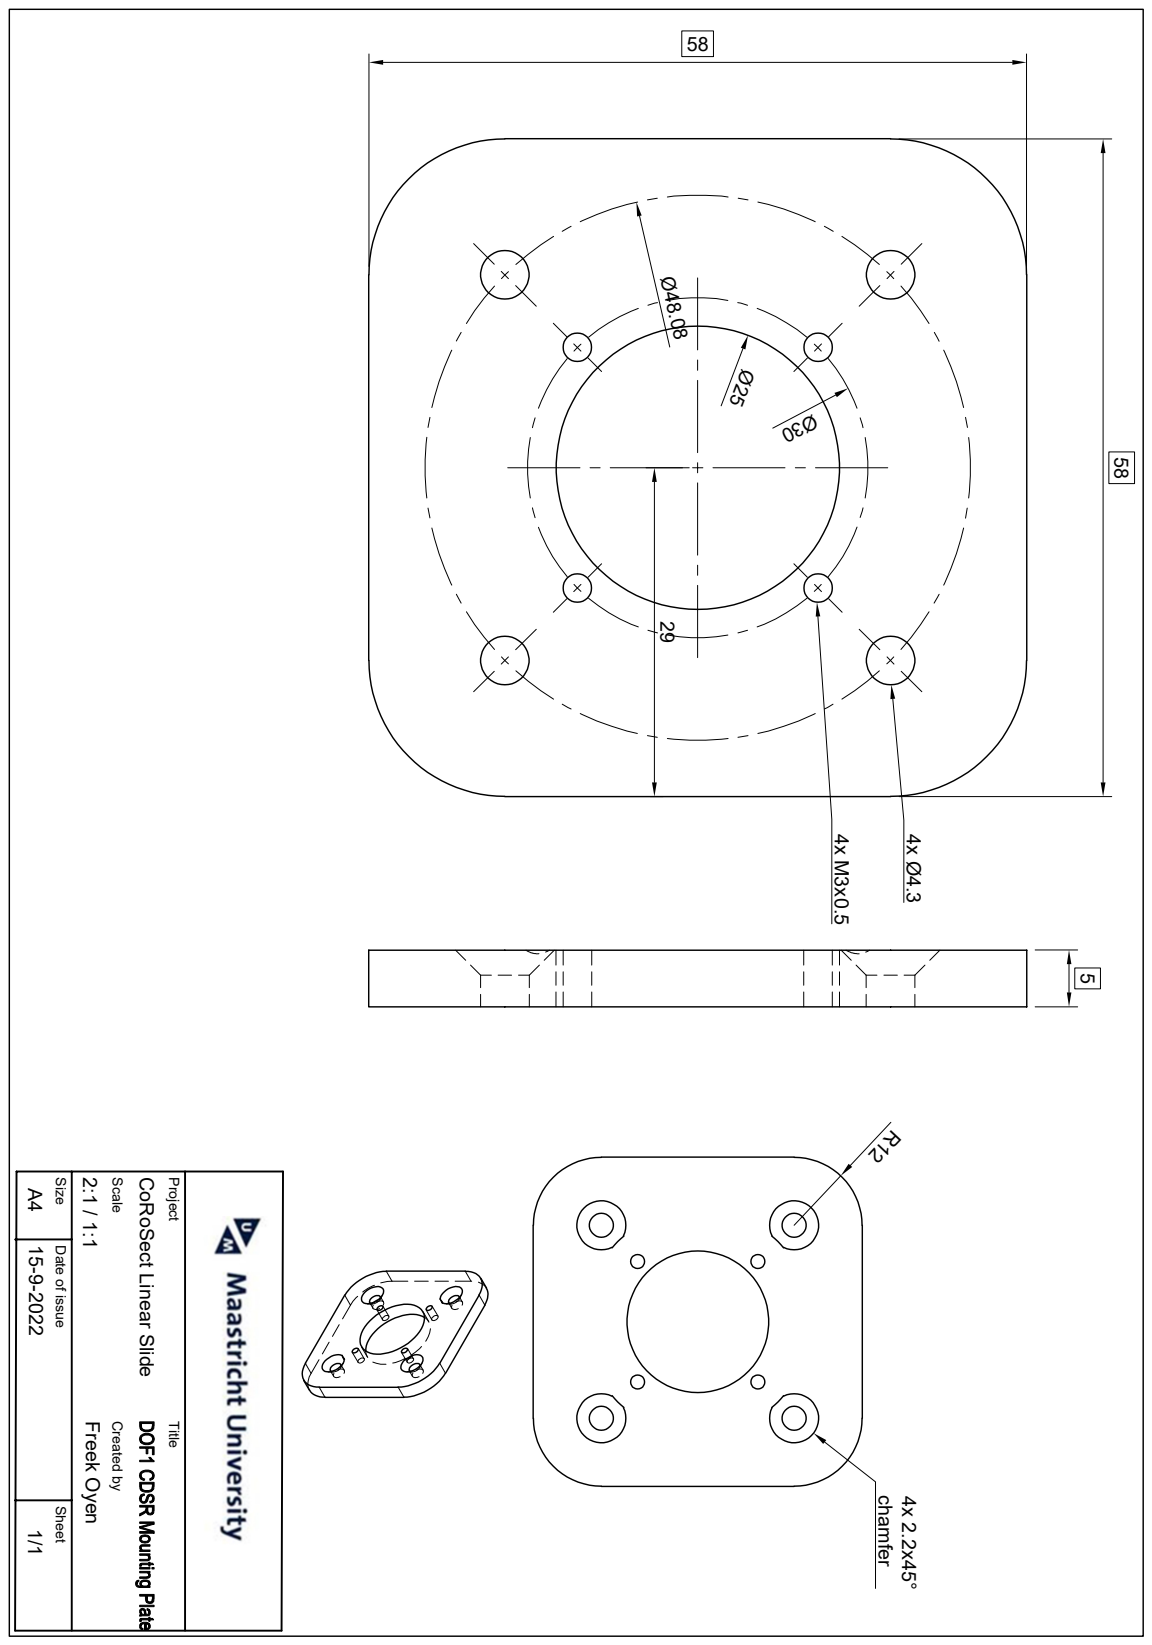
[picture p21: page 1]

Created by Project Date of issue Sheet Size Scale Title 15-9-2022 1/1 CoRoSect Linear Slide Freek Oyen 2:1 / 1:1 A4 Ø25Ø30 Ø48.08 4x M3x0.5 4x Ø4.3 58

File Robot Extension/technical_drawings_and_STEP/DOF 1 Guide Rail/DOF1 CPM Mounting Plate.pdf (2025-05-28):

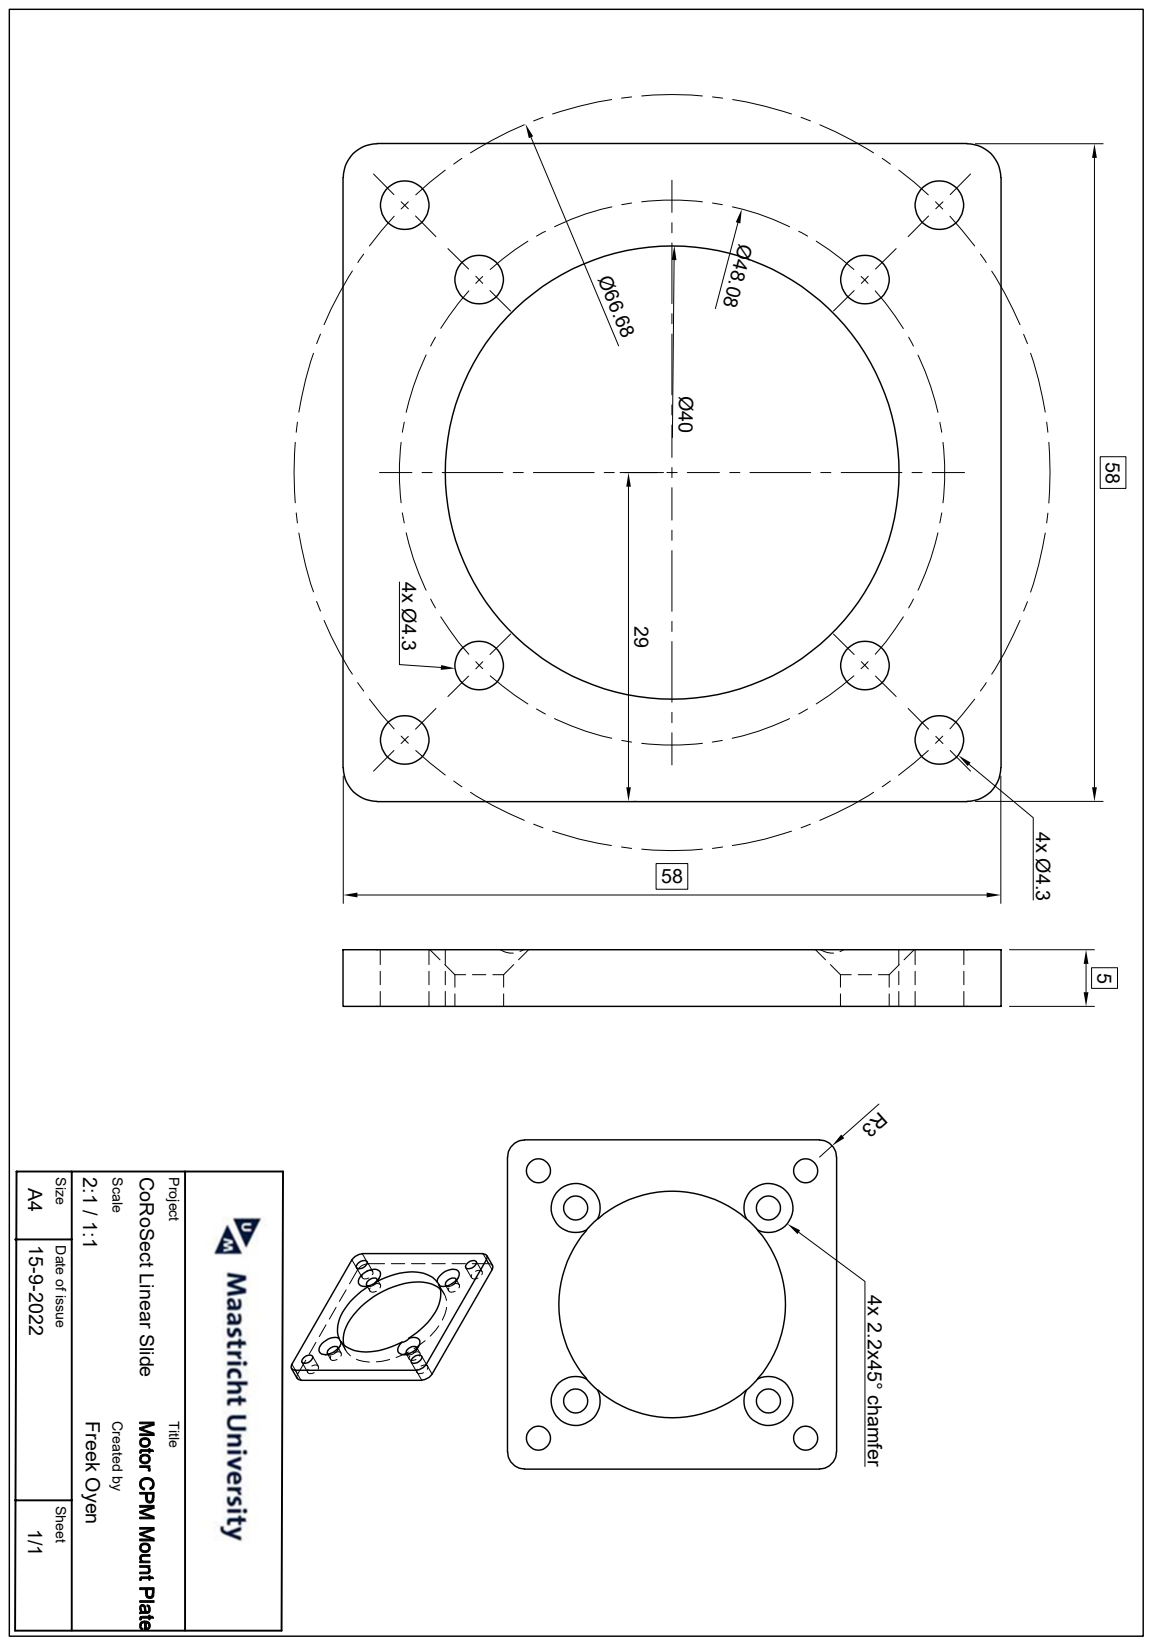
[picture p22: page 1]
5 R3 4x 2.2x45° chamfer

Created by Project Date of issue Sheet Size Scale Title 15-9-2022 1/1 CoRoSect Linear Slide Freek Oyen 2:1 / 1:1 A4 Ø40 Ø48 0. 8 Ø66.68 58

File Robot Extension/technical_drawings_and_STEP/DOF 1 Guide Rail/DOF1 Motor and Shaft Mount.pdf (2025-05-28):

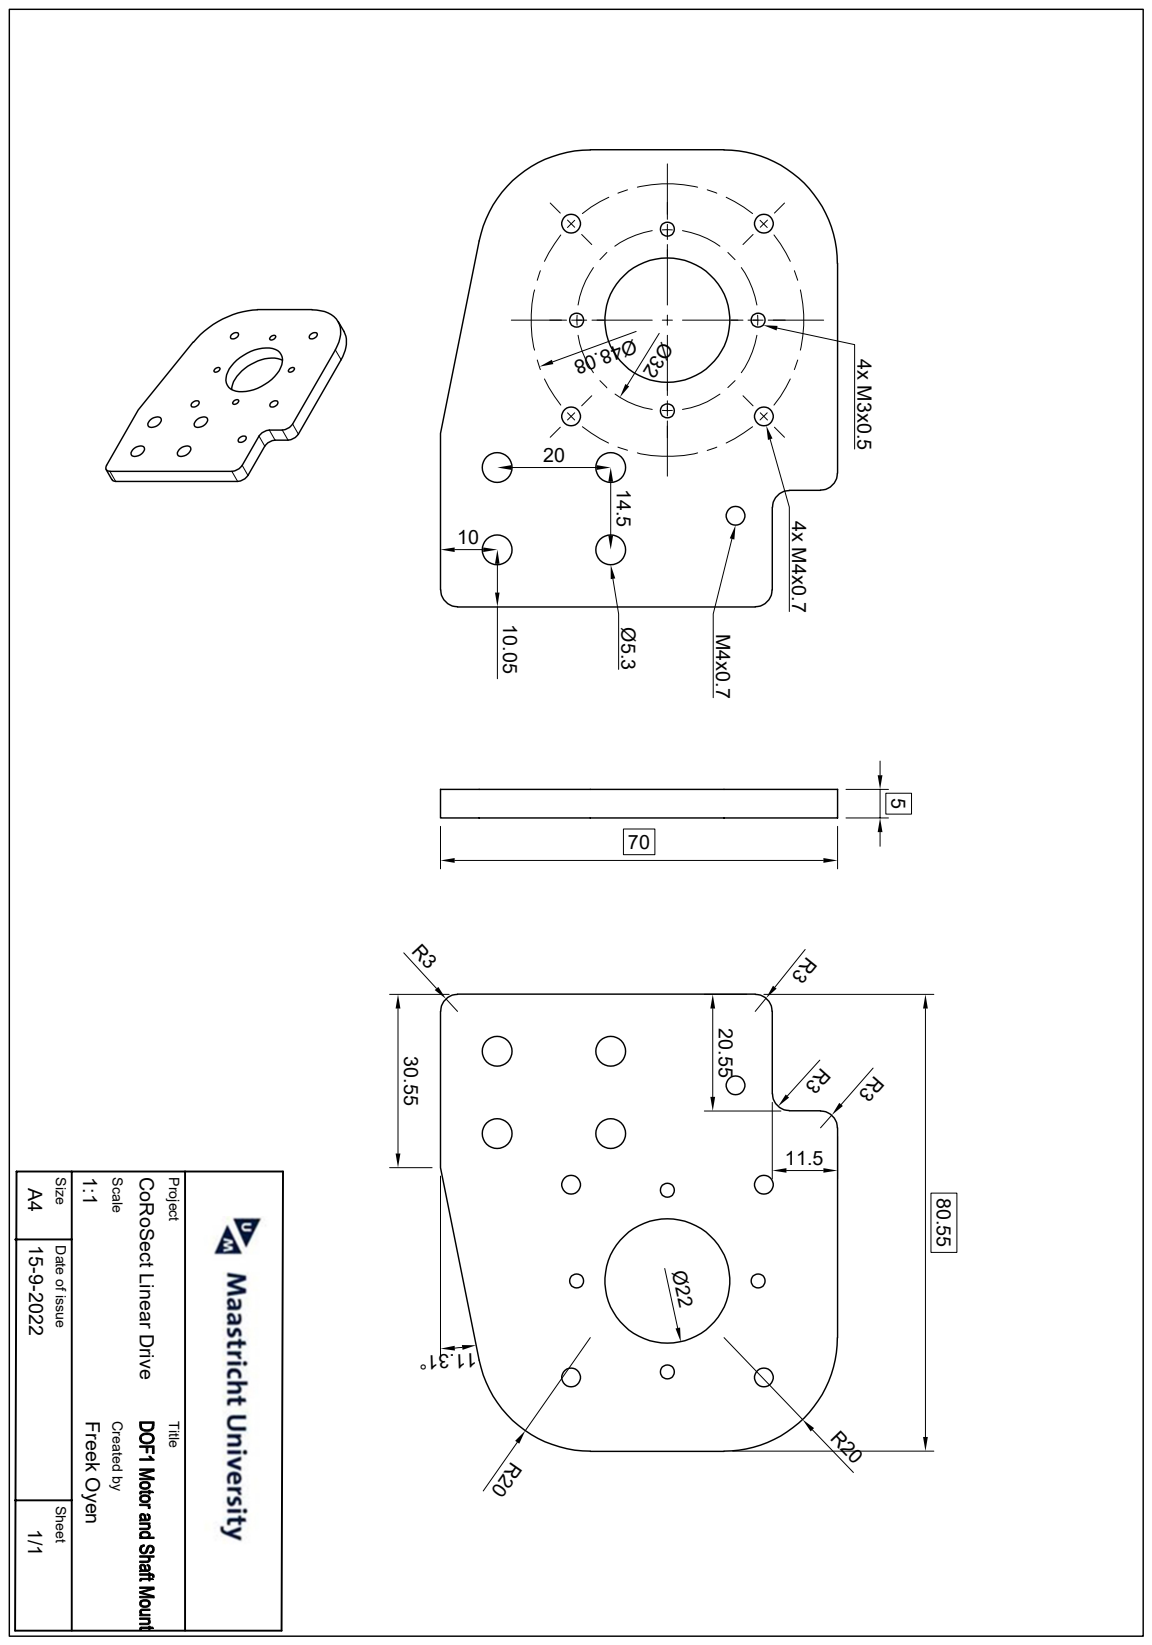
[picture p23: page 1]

Created by Project Date of issue Sheet Size Scale Title 15-9-2022 1/1 CoRoSect Linear Drive Freek Oyen 1:1A4 4x M3x0.5 Ø5.3 4 Ø Ø32 . 8 80 4x M4x0.7 M4x0.7 14.5

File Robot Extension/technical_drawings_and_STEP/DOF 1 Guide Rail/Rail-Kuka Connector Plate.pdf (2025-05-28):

14 2012.19 10

14 20

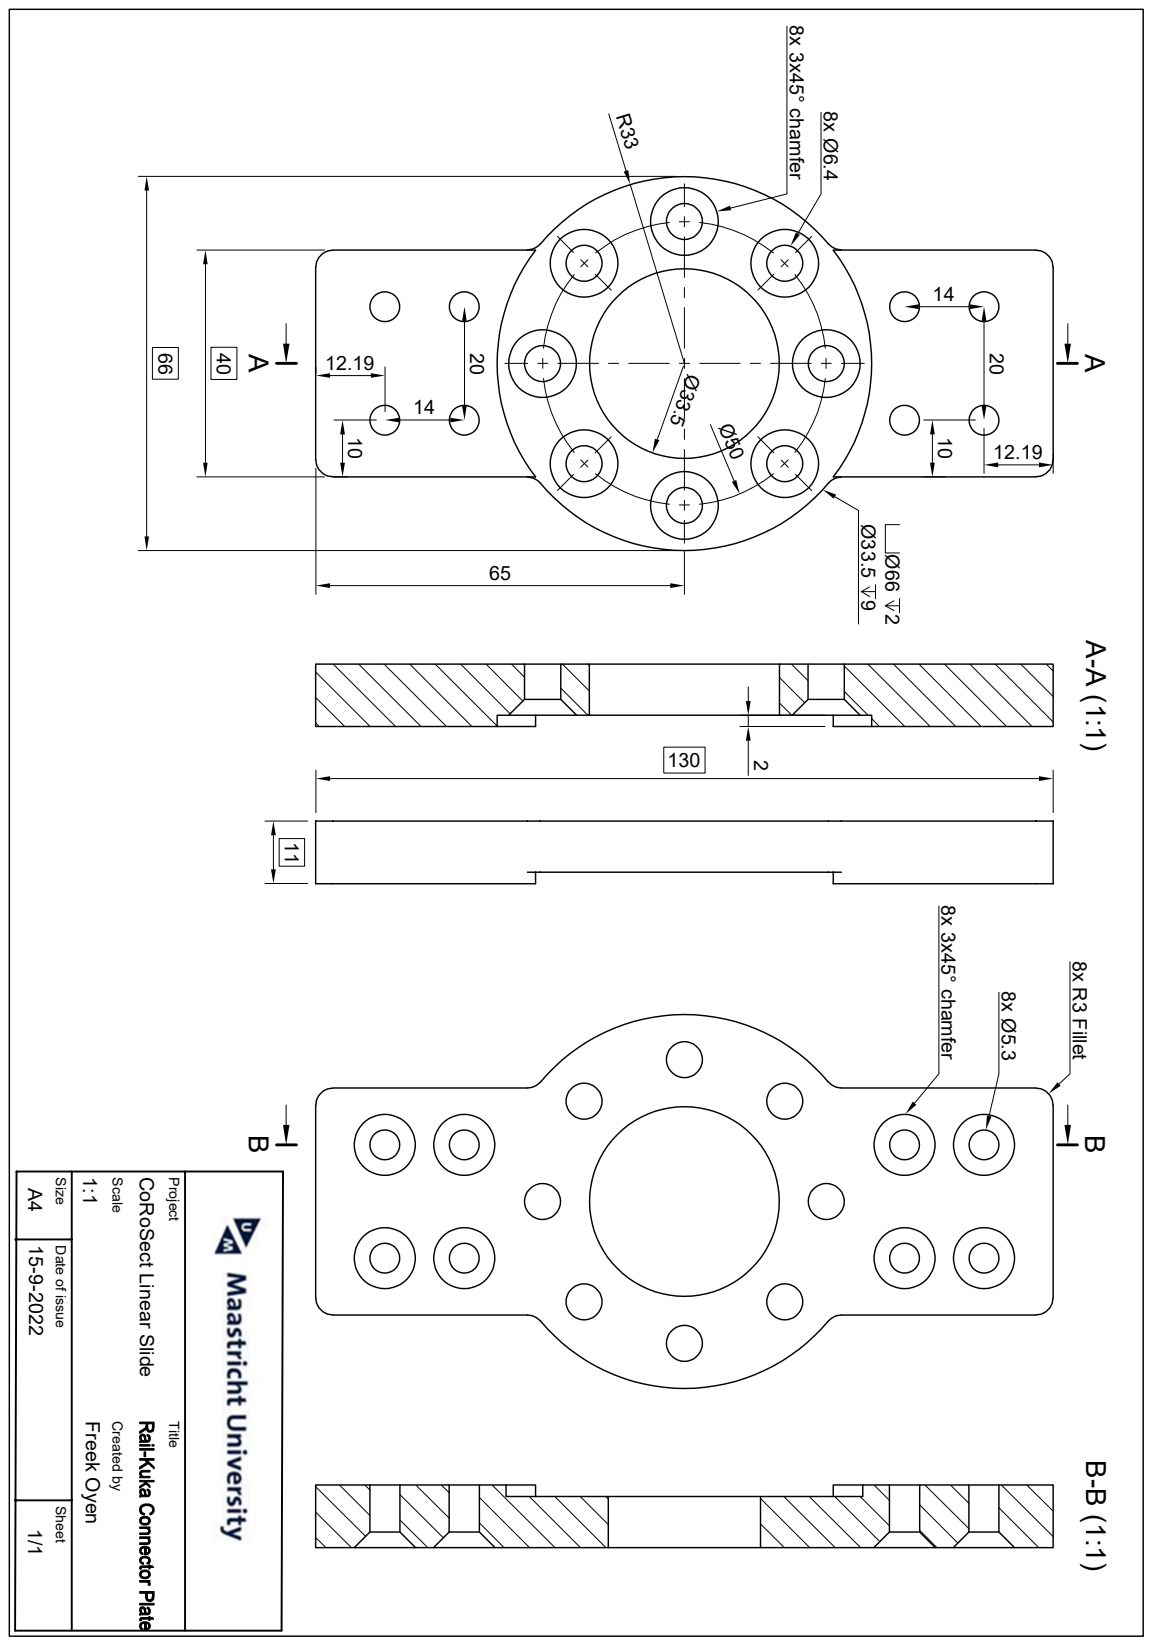
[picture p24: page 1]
8x R3 Fillet 8x Ø5.3 8x 3x45° chamfer 66

Created by Project Date of issue Sheet Size Scale Title 15-9-2022 1/1 CoRoSect Linear Slide Freek Oyen 1:1A4 AA A-A (1:1) Ø50 Ø3 5. 8x Ø6.4 8x 3x45° chamfer 40 R33

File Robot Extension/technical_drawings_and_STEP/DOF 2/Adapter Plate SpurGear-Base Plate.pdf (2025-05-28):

45 A | A A-A (2;1) 4.5 3.5 8 | Ø16 | Ø48.08 | 4x 4x45° chamfer 4x M5x0.8 8 3x Ø9 4.5

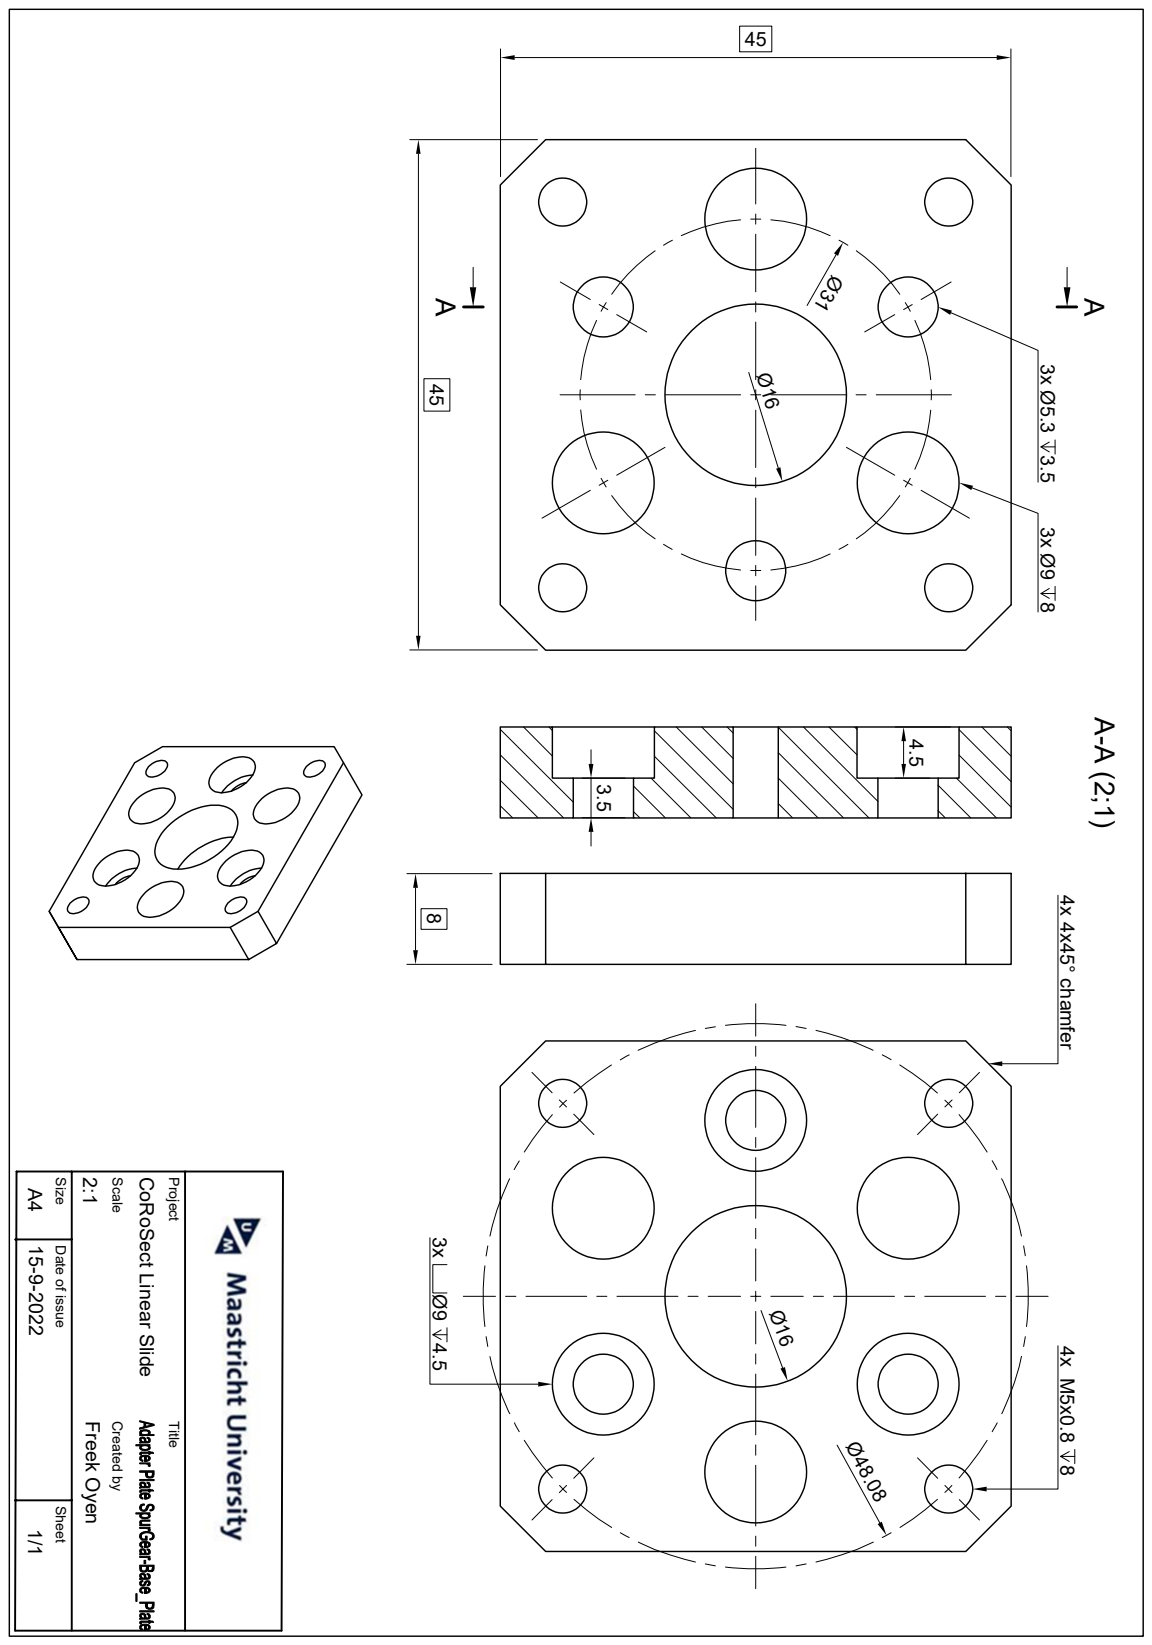
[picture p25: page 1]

Created by Project Date of issue Sheet Size Scale Title 15-9-2022 1/1 CoRoSect Linear Slide Freek Oyen 2:1A4 3x Ø9 8 3x Ø5.3 3.5 Ø16 Ø31 45

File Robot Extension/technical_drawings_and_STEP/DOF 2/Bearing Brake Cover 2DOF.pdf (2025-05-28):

32.5 | 3 | 36.21 3.35 | 0.35 Ø19 Ø17 | 3x Ø3.2 Ø17 | 3 3.35 | 3x R4.25
24 ²⁷.71 | Ø32 8 | 16

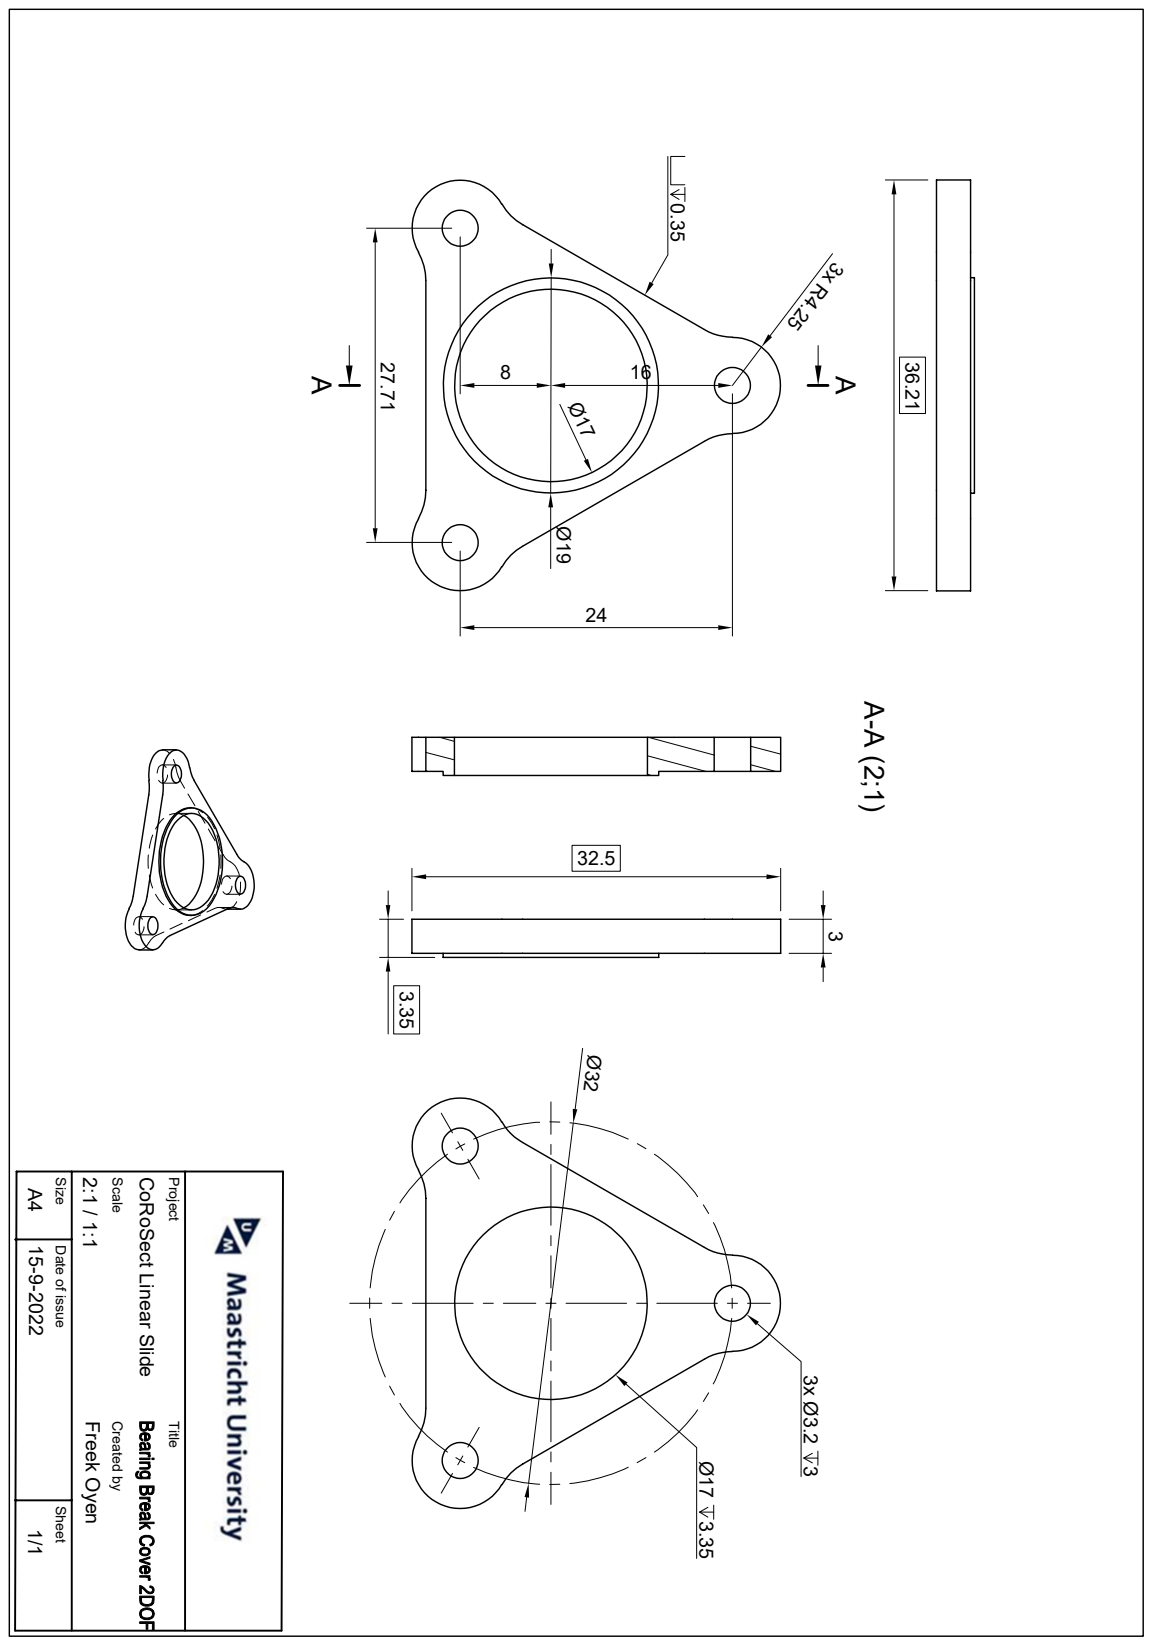
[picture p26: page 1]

Created by Project Date of issue Sheet Size Scale Title 15-9-2022 1/1 CoRoSect Linear Slide Freek Oyen 2:1 / 1:1 A4 AA A-A (2;1)

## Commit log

2025-05-28 Robot Extension design files
    [Adapter Plate RG6-Shaft.step, Adapter Plate SpurGear-Base Plate.step, Base Plate 2DOF.step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]
2025-05-28 URDF and simulation scripts
    [2 DOF.stl, 3DOF.stl, Guide Rail.stl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]
2025-05-28 extension stabilization secondary planning scene
    Adding launch files and ROS launchables to run with MoveIt!
    [fake_controllers.yaml]
